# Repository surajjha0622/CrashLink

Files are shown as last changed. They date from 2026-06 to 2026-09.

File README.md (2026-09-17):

# CrashLink

Hybrid **LTE + LoRa** Emergency Alert System for Reliable Accident Reporting

---

## Overview

CrashLink is a hybrid LTE + LoRa emergency alert system designed to transmit accident alerts even in areas with poor or no cellular network coverage.

The system consists of three different node types that work together to ensure emergency messages reach responders through either LTE or a LoRa relay network.

---

##  Problem

Road accidents frequently occur in remote areas where cellular connectivity is unreliable or unavailable. This can delay emergency notifications, increasing response time and reducing the chances of timely medical assistance.

---

##  Solution

CrashLink consists of three node types:

-  Vehicle Node
-  Relay Node
-  Gateway Node

When LTE coverage is available, alerts are sent directly over the cellular network.

If LTE is unavailable, CrashLink automatically switches to a LoRa relay network, forwarding the emergency message until it reaches a Gateway Node.

---

#  System Architecture

<p align="center">
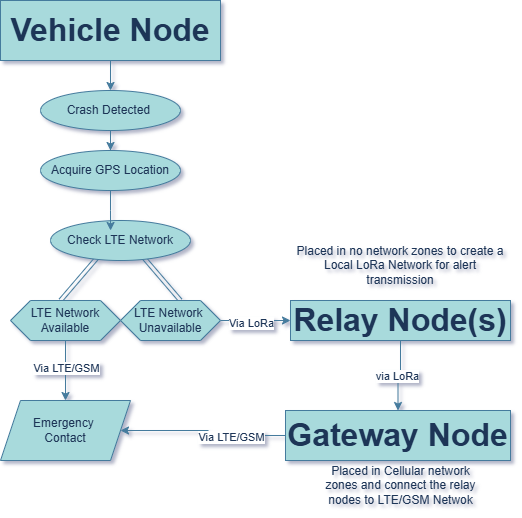
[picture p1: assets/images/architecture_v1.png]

</p>

---

#  Vehicle Node

### PCB Views

| Top | Bottom |
|---|---|
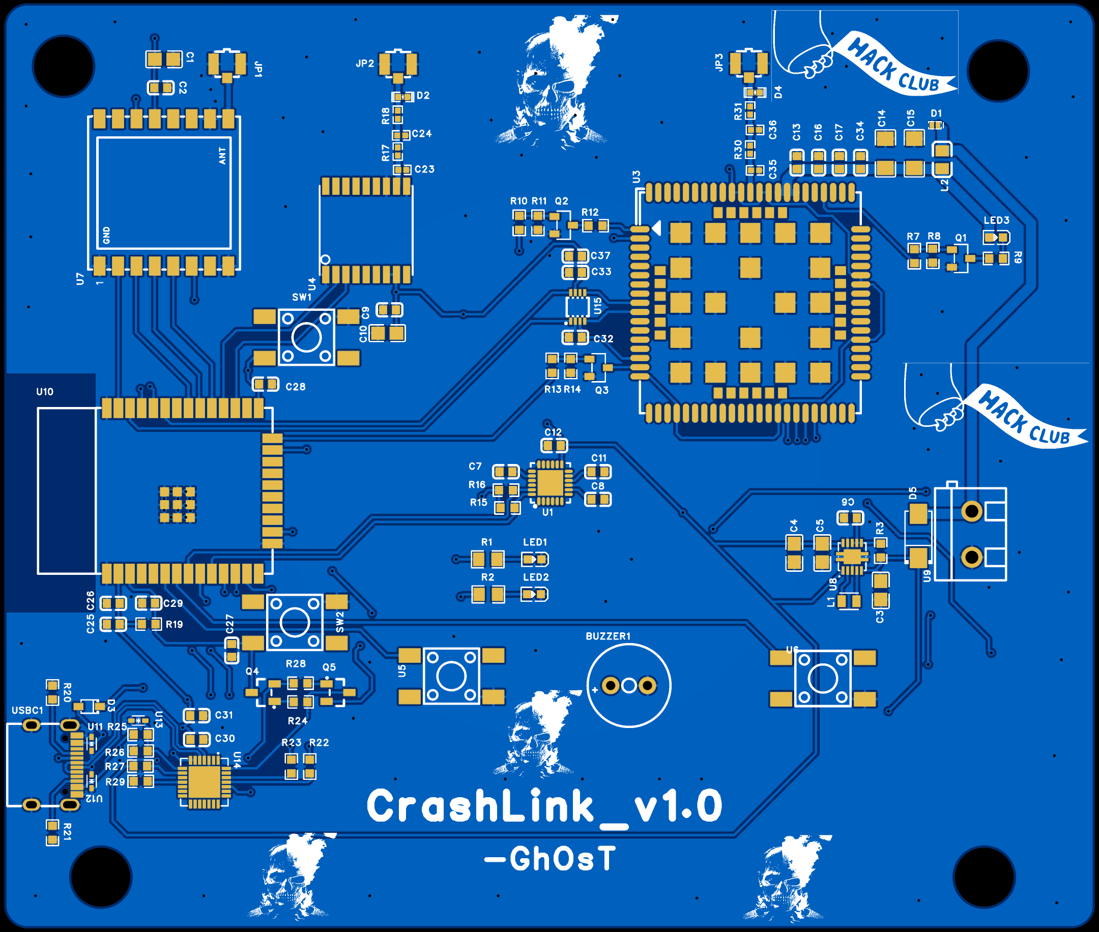
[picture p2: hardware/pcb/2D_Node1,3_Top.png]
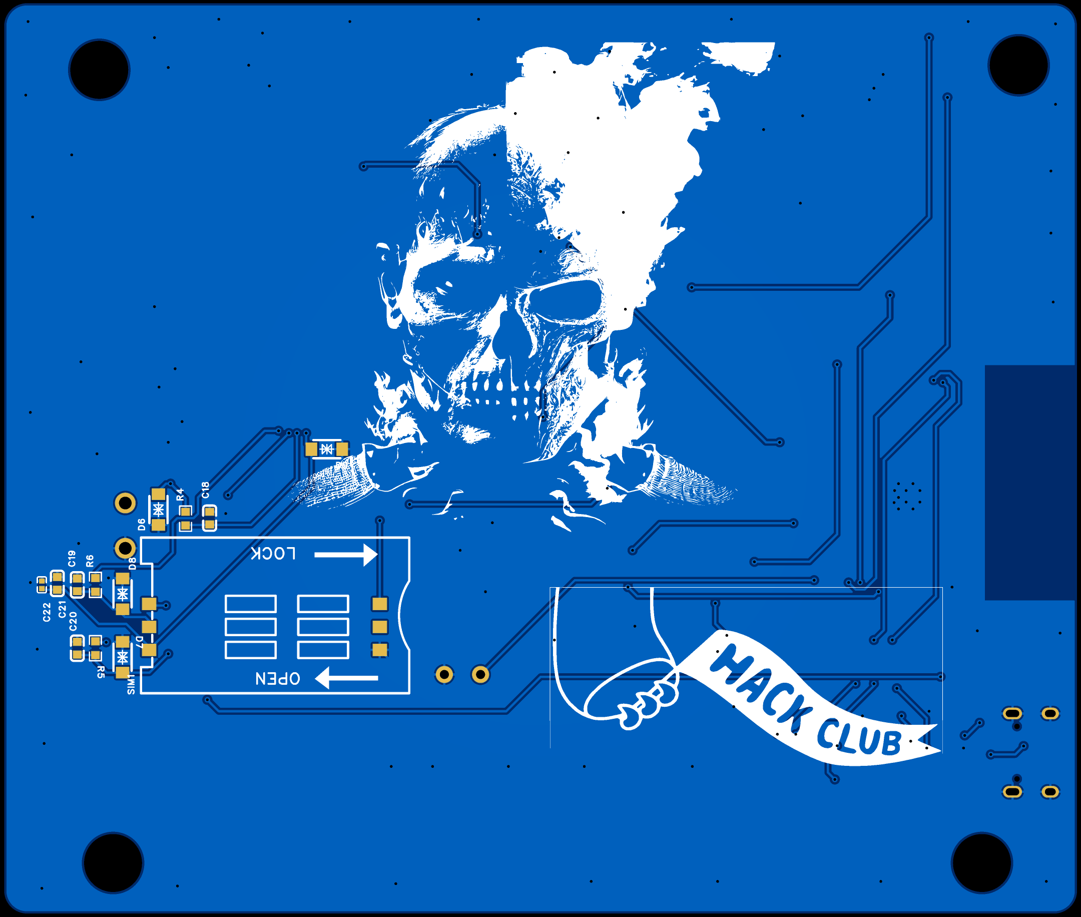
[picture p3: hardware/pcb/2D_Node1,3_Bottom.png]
|  |  |

### 3D Model

<p align="center">
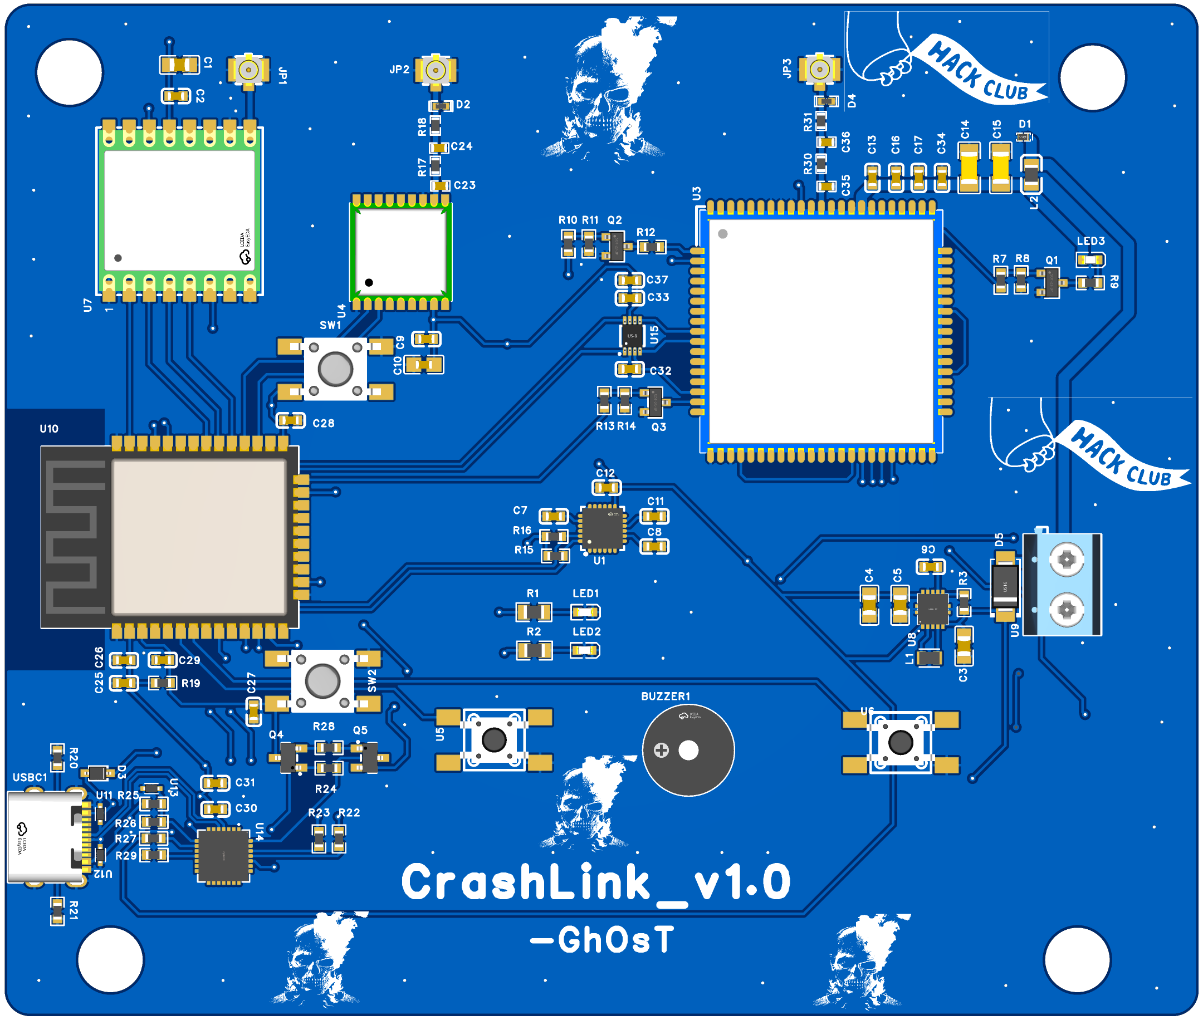
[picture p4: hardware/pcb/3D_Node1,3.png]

</p>

### Enclosure

<p align="center">
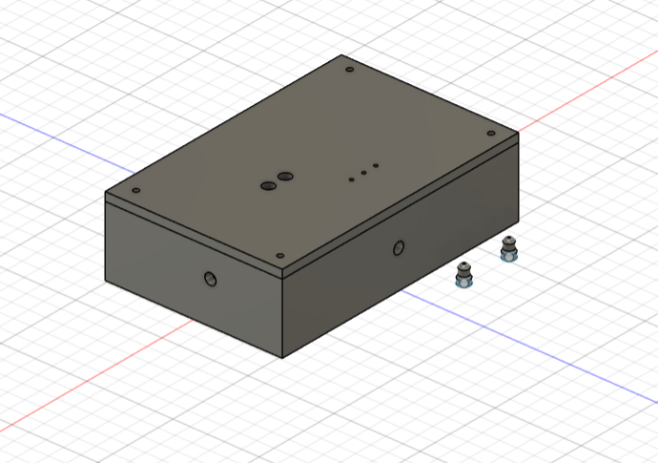
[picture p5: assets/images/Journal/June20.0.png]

</p>

---

#  Relay Node

### PCB Views

| Top | Bottom |
|---|---|
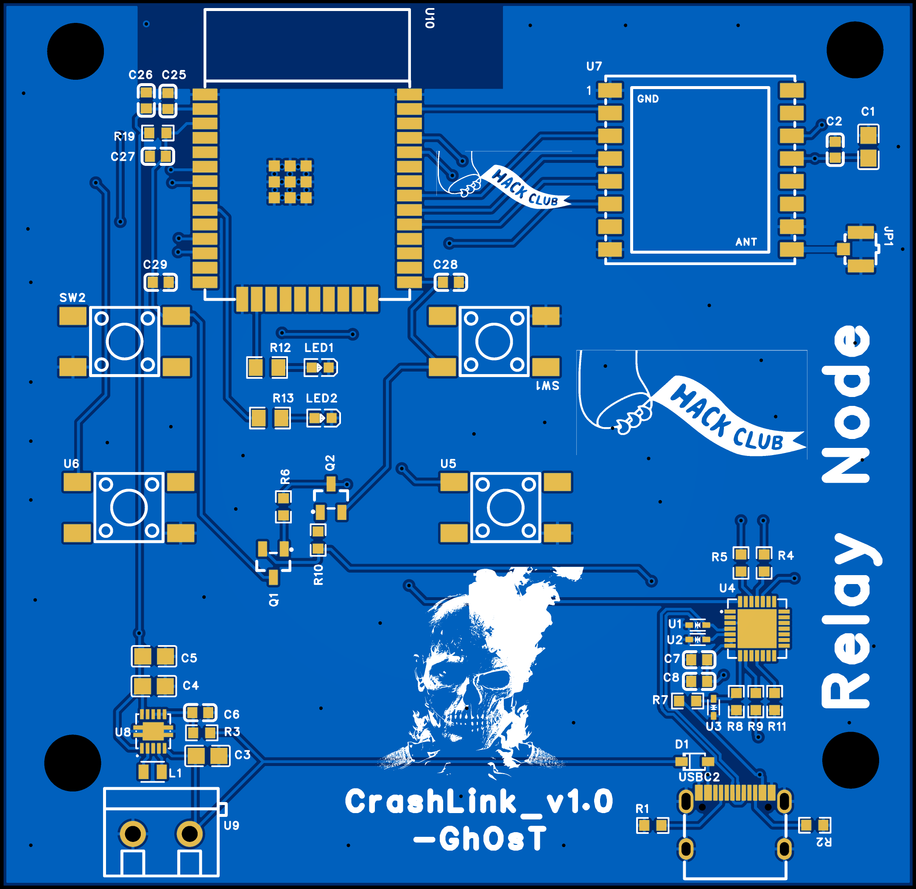
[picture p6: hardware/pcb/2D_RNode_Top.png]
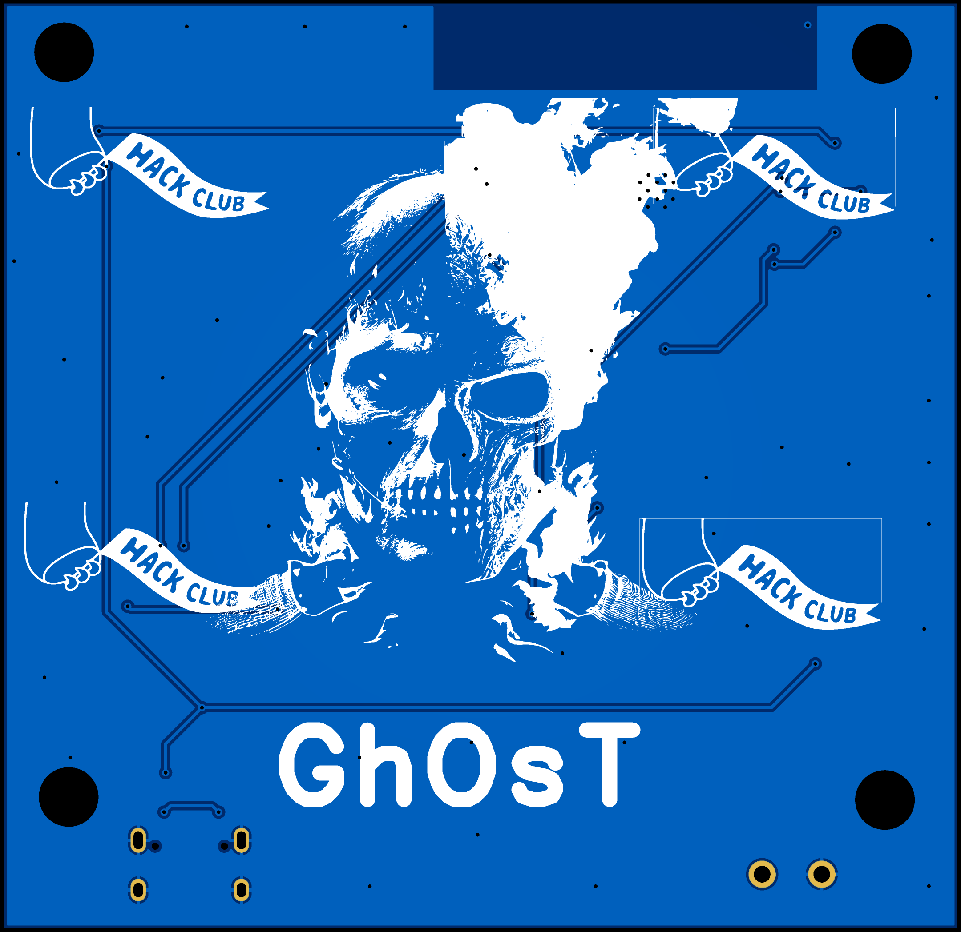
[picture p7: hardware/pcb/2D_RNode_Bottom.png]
|  |  |

### 3D Model

<p align="center">
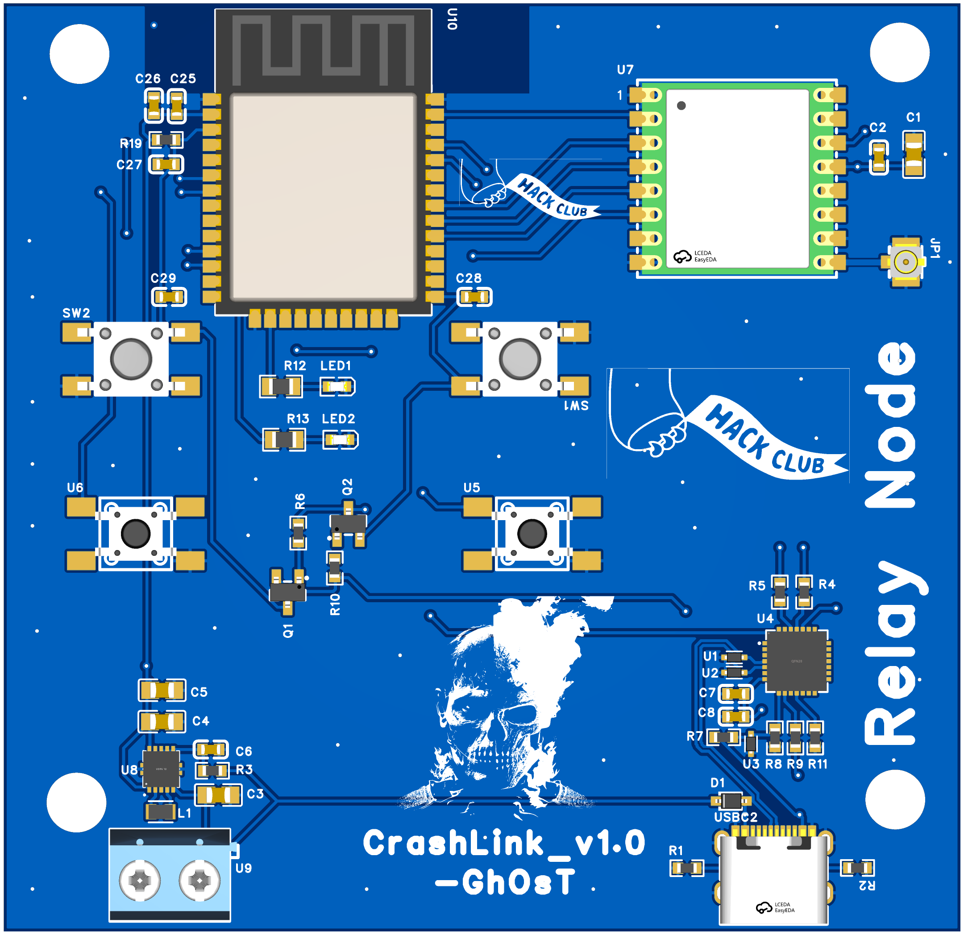
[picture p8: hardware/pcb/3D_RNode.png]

</p>

### Enclosure

<p align="center">
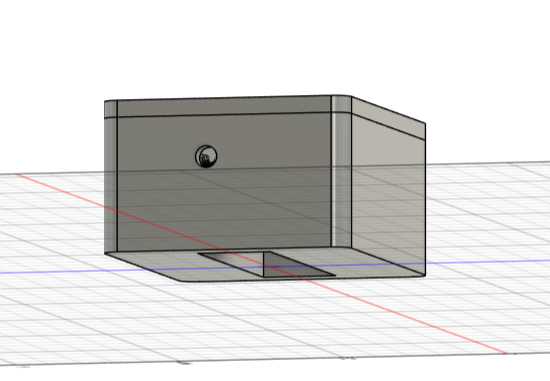
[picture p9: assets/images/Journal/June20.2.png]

</p>

---

#  Gateway Node

### PCB Views

| Top | Bottom |
|---|---|
|  |  |

### 3D Model

<p align="center">

</p>

### Enclosure

<p align="center">
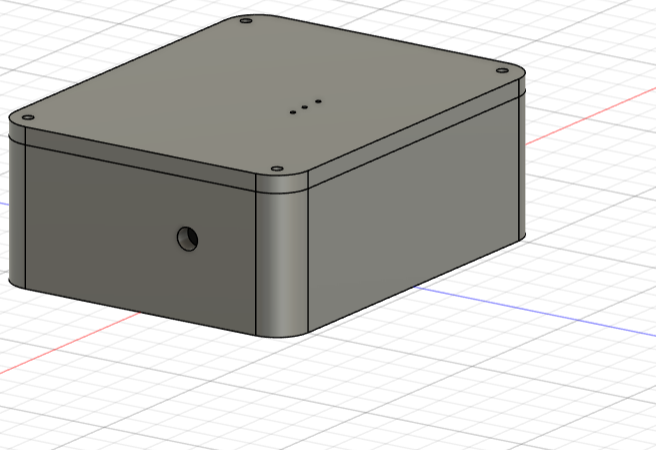
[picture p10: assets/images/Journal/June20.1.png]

</p>

---

#  BOM

## Core Electronics
 | Component | Qty | Purpose | Estimated Cost($) |
 |-----------|-----|---------|-------------------|
 | ESP32 | 3 | vehicle, Relay, Gateway controller| $15 |
 | SX1278 LoRa Module | 3 | LoRa communication  | $18 |
 | A7670 LTE Module | 2 | Vehicle LTE, Gateway LTE | $28 |
 | MAX10S GPS Module | 1 | Vehicle GPS | $12 |
 | MPU6050 | 1 | Vehicle | $4 |
 | Buck converter | 5 | Vehicle 2, Relay 1, Gateway 2| $10 |
 
 ## RF Components
 | Component | Qty | Purpose | Estimated Cost($) |
 |-----------|-----|---------|-------------------|
 | LoRa antenna | 3 | vehicle, Relay, Gateway | $9 |
 | LTE Antenna | 2 | Vehicle, Relay, Gateway | $10 |
 | U.FL/IPEX Cable | 8 | Antenna connections | $16 |

 ## Power System
 | Component | Qty | Purpose | Estimated Cost($) |
 |-----------|-----|---------|-------------------|
 | Li-ion Battery | 3 | Power source 1 each for Vehicle, Relay & Gateway | $25 |
 | Battery Connector/Holder | 4 | Battery Integration | $3 |
 | BMS/Protection module | 3 | Battery protection | $4 |

## PCB Fabrication
| Component | Qty | Purpose | Estimated Cost($) |
 |-----------|-----|---------|-------------------|
 | Vehicle Node PCB | 5 | Protoype fabrication |$15  |
 | Relay Node PCB | 5 | Protoype fabrication | $10 |
 | Gateway Node PCB | 5 | Protoype fabrication | $15 |

## Mechanical Components
 | Component | Qty | Purpose | Estimated Cost($) |
 |-----------|-----|---------|-------------------|
 |3D Printed Vehicle Enclosure | 1 | Housing | $10 |
 |3D Printed Vehicle Enclosure | 1 | Housing | $8 |
 |3D Printed Vehicle Enclosure | 1 | Housing | $10 |
 | M3 Screws Nuts & Standoffs | 1 Kit | assembly | $2 |

## Assembly Components
 
 | Component | Qty | Purpose | Estimated Cost($) |
 |-----------|-----|---------|-------------------|
 | LEDs | 10 | status indication  | $1  |
 | Push Buttons | 5 | User interaction | $1 |
 | Header pins | 2 Packs | Module connections| $3 |
 | JST connectors | 10 | battery and Power connections| $2 |
 | Screw terminals | 10 | Wiring | $2 |
 | Jumper Wires | 1 Kit | Prototyping | $3 |
 | Heat Shrink Tubing | 1 Kit | wire insulation | $4 |

 ## Assembly Tools
 | Component | Qty | Purpose | Estimated Cost($) |
 |-----------|-----|---------|-------------------|
 | Soldering Station | 1 | PCB assembly | $45 |
 | Solder Wire | 1 | Soldering | $5 |
 | Flux | 1 | Soldering | $5 |
 | Fume Extractor | 1 | Indoor solering safety | $20 |

## Notes
 - Quantities may be adjusted during prototype testing and validiation.

 ## Estimates Budget
 | Category | Estimated Cost ($) |
 |----------|--------------------|
 | Core Electronics | $87 |
 | RF Components | $35 |
 | Power System | $32 |
 | PCB Fabrication | $40 |
 | Mechanical Components | $30 |
 | Assembly Components | $16 | 
 | Assembly Tools | $75 |
 | **Total** | $315 |

#  License

This project is licensed under the MIT License.

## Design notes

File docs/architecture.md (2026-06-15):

# Crashlink Architecture

## Goal

Crashlink is a hybrid emergency alert system for vehicles.

Architecture

when cellular network is available then it uses LTE/GSM.

when network is not available in the area in consideration then it uses LoRa relay network to send the alert to nearest Gateway node.

Gateway node then transfers the alert via LTE/GSM.
Gateway nodes are strategically placed in the network available zones only.

## Vehicle node

 It detects the crash using the inputs from IMU and collect the GPS data from the GPS module.
 Now it scans for the availability of cellular network. If the network is available then it sends the alert signal via LTE and if the cellular coverage is not there then it sends the alert via LoRa over the LoRa network.

 ## Relay Node(s)
 It Recieves alerts from vehicle Node and Retransmits it if certain conditions are met.
 The Relay node(s) covers the area of no cellular coverage, acting as a backup fallback network and a bridge between the Vehicle Node and the Gateway Node.

 ## Gateway Node

 It is strategically placed to cover both the Relay node and cellular coverage in its range.
 This enable it to recieve the alerts from the Relay nodes and send alert over to cellular network.

Thus the system uses the cellular network coverage which is already available while also fills the gaps of no cellular connectivity and that too at low cost.

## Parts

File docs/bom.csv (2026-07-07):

Category | Component | Qty | Purpose | Estimated Cost ($)
Core Electronics | ESP32 | 4 | Vehicle, Relay, Gateway and spare controller | 20
Core Electronics | SX1278 LoRa Module | 4 | LoRa communication and spare | 24
Core Electronics | A7670 LTE Module | 3 | Vehicle LTE, Gateway LTE and spare | 40
Core Electronics | NEO-6M GPS Module | 2 | Vehicle GPS and spare | 12
Core Electronics | MPU6050 | 2 | Vehicle and spare | 4
Core Electronics | Buck Converter | 5 | Vehicle 2, Relay 1, Gateway 2 | 10
RF Components | LoRa Antenna | 4 | Vehicle, Relay, Gateway and spare | 12
RF Components | LTE Antenna | 3 | Vehicle, Relay, Gateway and spare | 15
RF Components | U.FL/IPEX Cable | 8 | Antenna connections | 16
Power System | Li-ion Battery | 6 | Power source (2 each for Vehicle, Relay & Gateway) | 25
Power System | Battery Connector/Holder | 4 | Battery integration | 3
Power System | BMS/Protection Module | 3 | Battery protection | 4
PCB Fabrication | Vehicle Node PCB | 5 | Prototype fabrication | 15
PCB Fabrication | Relay Node PCB | 5 | Prototype fabrication | 10
PCB Fabrication | Gateway Node PCB | 5 | Prototype fabrication | 15
Mechanical Components | 3D Printed Vehicle Enclosure | 1 | Housing | 10
Mechanical Components | 3D Printed Relay Enclosure | 1 | Housing | 8
Mechanical Components | 3D Printed Gateway Enclosure | 1 | Housing | 10
Mechanical Components | M3 Screws, Nuts & Standoffs | 1 Kit | Assembly | 2
Assembly Components | LEDs | 10 | Status indication | 1
Assembly Components | Push Buttons | 5 | User interaction | 1
Assembly Components | Header Pins | 2 Packs | Module connections | 3
Assembly Components | JST Connectors | 10 | Battery and power connections | 2
Assembly Components | Screw Terminals | 10 | Wiring | 2
Assembly Components | Jumper Wires | 1 Kit | Prototyping | 3
Assembly Components | Heat Shrink Tubing | 1 Kit | Wire insulation | 4
Assembly Tools | Soldering Iron | 1 | PCB assembly | 25
Assembly Tools | Solder Wire | 1 | Soldering | 5
Assembly Tools | Flux | 1 | Soldering | 5
Assembly Tools | Fume Extractor | 1 | Indoor soldering safety | 20

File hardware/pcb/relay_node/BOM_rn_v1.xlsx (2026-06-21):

No. | Quantity | Comment | Designator | Footprint | Value | Manufacturer Part | Manufacturer | Supplier Part | Supplier
1 | 5 | 10uF | C1,C3,C4,C5,C9 | C0805 | 10uF | CL21A106KAYNNNE | SAMSUNG(三星) | C15850 | LCSC
2 | 3 | 100nF | C2,C6,C10 | C0603 | 100nF | CC0603KRX7R9BB104 | YAGEO(国巨) | C14663 | LCSC
3 | 1 | 6GHz | JP1 | RF-SMD_FRF05002-JSS103M | 6GHz | U.FL-R-SMT-1(80) | HRS(广濑) | C88374 | LCSC
4 | 1 | 2.2uH | L1 | IND-SMD_L2.0-W1.2-MWTC201208S2R2MT | 2.2uH | APH201210C2R2MP01 | APV(爱普微) | C42455275 | LCSC
5 | 2 | XL-1608SURC-06 | LED1,LED2 | LED0603-RD_RED |  | XL-1608SURC-06 | XINGLIGHT(成兴光) | C965799 | LCSC
6 | 2 | 330mΩ | R1,R2 | R0805 | 330mΩ | 0805W8J033KT5E | UNI-ROYAL(厚声) | C31973 | LCSC
7 | 1 | 100Ω | R3 | R0603 | 100Ω | 0603WAF1000T5E | UNI-ROYAL(厚声) | C22775 | LCSC
8 | 1 | ESP32-S3 | U2 | COMM-TH_43.2-W17.8-P2.54_ESP32-S3 |  | ESP32-S3 | Waveshare(微雪电子) | C22438991 | LCSC
9 | 1 | RFM95W-915S2 | U7 | WIRELM-SMD_16P-L16.0-W16.0-P2.00_LORA-CC68-915MHZ-TCXO |  | RFM95W-915S2 | RF Solutions | C6760738 | LCSC
10 | 1 | TPS63001DRCR | U8 | VSON-10_L3.0-W3.0-P0.50-TL-EP_TPS62410DRCR |  | TPS63001DRCR | TI(德州仪器) | C28060 | LCSC
11 | 1 | KF301-5.0-2P | U9 | CONN-TH_P5.00_KF301-5.0-2P |  | KF301-5.0-2P | KEFA(科发) | C474881 | LCSC

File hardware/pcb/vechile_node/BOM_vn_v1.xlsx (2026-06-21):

No. | Quantity | Comment | Designator | Footprint | Value | Manufacturer Part | Manufacturer | Supplier Part | Supplier
1 | 1 | 2.7kHz | BUZZER1 | BUZ-TH_BD9.0-P4.00-D0.6-FD | 2.7kHz | QMB-09B-03 | 华能 | C96256 | LCSC
2 | 7 | 10uF | C1,C3,C4,C5,C7,C9,C11 | C0805 | 10uF | CL21A106KAYNNNE | SAMSUNG(三星) | C15850 | LCSC
3 | 7 | 100nF | C2,C6,C8,C10,C12,C16,C21 | C0603 | 100nF | CC0603KRX7R9BB104 | YAGEO(国巨) | C14663 | LCSC
4 | 1 | 10pF | C13 | C0603 | 10pF | CL10C100JB8NNNC | SAMSUNG(三星) | C1634 | LCSC
5 | 2 | 100uF | C14,C15 | C1206 | 100uF | CL31A107MQHNNNE | SAMSUNG(三星) | C15008 | LCSC
6 | 1 | 1uF | C17 | C0603 | 1uF | CL10A105KB8NNNC | SAMSUNG(三星) | C15849 | LCSC
7 | 3 | 22pF | C18,C19,C20 | C0603 | 22pF | CL10C220JB8NNNC | SAMSUNG(三星) | C1653 | LCSC
8 | 1 | 33pF | C22 | C0402 | 33pF | C0402T330G5GCLTU | KEMET(基美) | C2416757 | LCSC
9 | 1 | 1N4148SOD-323 | D1 | SOD-323_L1.7-W1.3-LS2.5-RD |  | 1N4148SOD-323 | JKSEMI(金开盛) | C2972761 | LCSC
10 | 3 | 6GHz | JP1,JP2,JP3 | RF-SMD_FRF05002-JSS103M | 6GHz | U.FL-R-SMT-1(80) | HRS(广濑) | C88374 | LCSC
11 | 1 | 2.2uH | L1 | IND-SMD_L2.0-W1.2-MWTC201208S2R2MT | 2.2uH | APH201210C2R2MP01 | APV(爱普微) | C42455275 | LCSC
12 | 1 | BLM21PG300SN1D | L2 | L0805 |  | BLM21PG300SN1D | muRata(村田) | C16903 | LCSC
13 | 2 | XL-1608SURC-06 | LED1,LED2 | LED0603-RD_RED |  | XL-1608SURC-06 | XINGLIGHT(成兴光) | C965799 | LCSC
14 | 1 | 19-217/GHC-YR1S2/3T | LED3 | LED0603-RD |  | 19-217/GHC-YR1S2/3T | EVERLIGHT(亿光) | C72043 | LCSC
15 | 3 | MMBT3904(RANGE:100-300) | Q1,Q2,Q3 | SOT-23-3_L2.9-W1.3-P1.90-LS2.4-BR |  | MMBT3904(RANGE:100-300) | CJ(江苏长电/长晶) | C20526 | LCSC
16 | 2 | 330mΩ | R1,R2 | R0805 | 330mΩ | 0805W8J033KT5E | UNI-ROYAL(厚声) | C31973 | LCSC
17 | 1 | 100Ω | R3 | R0603 | 100Ω | 0603WAF1000T5E | UNI-ROYAL(厚声) | C22775 | LCSC
18 | 3 | 22Ω | R4,R5,R6 | R0603 | 22Ω | 0603WAF220JT5E | UNI-ROYAL(厚声) | C23345 | LCSC
19 | 5 | 4.7kΩ | R7,R10,R13,R15,R16 | R0603 | 4.7kΩ | 0603WAF4701T5E | UNI-ROYAL(厚声) | C23162 | LCSC
20 | 3 | 47kΩ | R8,R11,R14 | R0603 | 47kΩ | 0603WAF4702T5E | UNI-ROYAL(厚声) | C25819 | LCSC
21 | 2 | 1kΩ | R9,R12 | R0603 | 1kΩ | 0603WAF1001T5E | UNI-ROYAL(厚声) | C21190 | LCSC
22 | 1 | CCM033001LFTR102 | SIM1 | SIM-SMD_CCM033001LFTR102 |  | CCM033001LFTR102 |  | C9900003292 | LCSC
23 | 1 | MPU-6050 | U1 | QFN-24_L4.0-W4.0-P0.50-BL-EP2.7 |  | MPU-6050 | TDK InvenSense(应美盛) | C24112 | LCSC
24 | 1 | ESP32-S3 | U2 | COMM-TH_43.2-W17.8-P2.54_ESP32-S3 |  | ESP32-S3 | Waveshare(微雪电子) | C22438991 | LCSC
25 | 1 | A7670C-LANS | U3 | LGA-124_L24.0-W24.0-P1.0-A7670C-LASS |  | A7670C-LANS | SIMCOM(芯讯通无线科技) | C18548274 | LCSC
26 | 1 | NEO-6M-0-001 | U4 | GPSM-SMD_24P-L16.0-W12.2-P1.10 |  | NEO-6M-0-001 | U-BLOX(优北罗) | C32413118 | LCSC
27 | 2 | YZA-056-5.0 | U5,U6 | SW-SMD_4P-L4.5-W4.5-P3.00-LS6.8 |  | YZA-056-5.0 | YIZHI(逸致) | C49108648 | LCSC
28 | 1 | RFM95W-915S2 | U7 | WIRELM-SMD_16P-L16.0-W16.0-P2.00_LORA-CC68-915MHZ-TCXO |  | RFM95W-915S2 | RF Solutions | C6760738 | LCSC
29 | 1 | TPS63001DRCR | U8 | VSON-10_L3.0-W3.0-P0.50-TL-EP_TPS62410DRCR |  | TPS63001DRCR | TI(德州仪器) | C28060 | LCSC
30 | 1 | KF301-5.0-2P | U9 | CONN-TH_P5.00_KF301-5.0-2P |  | KF301-5.0-2P | KEFA(科发) | C474881 | LCSC

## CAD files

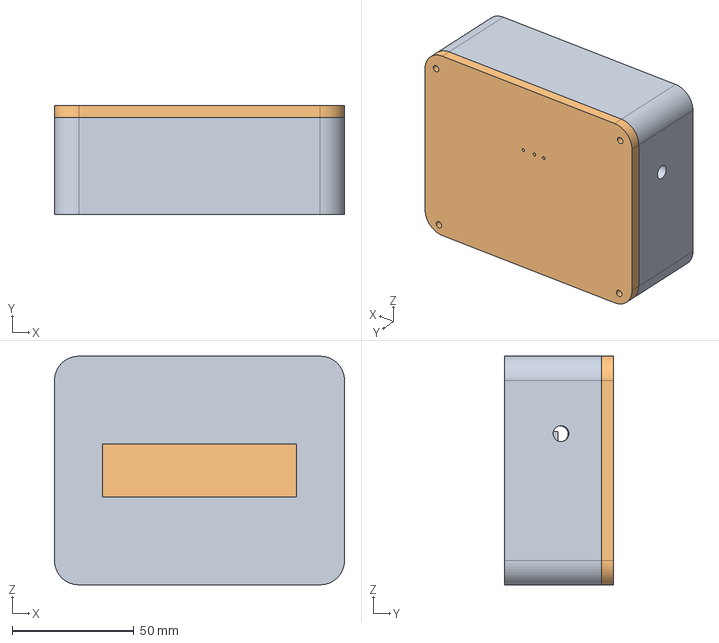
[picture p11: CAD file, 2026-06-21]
hardware/cad/gateway_node/GatewayCase_v1.step
119.3 x 45.0 x 94.1 mm

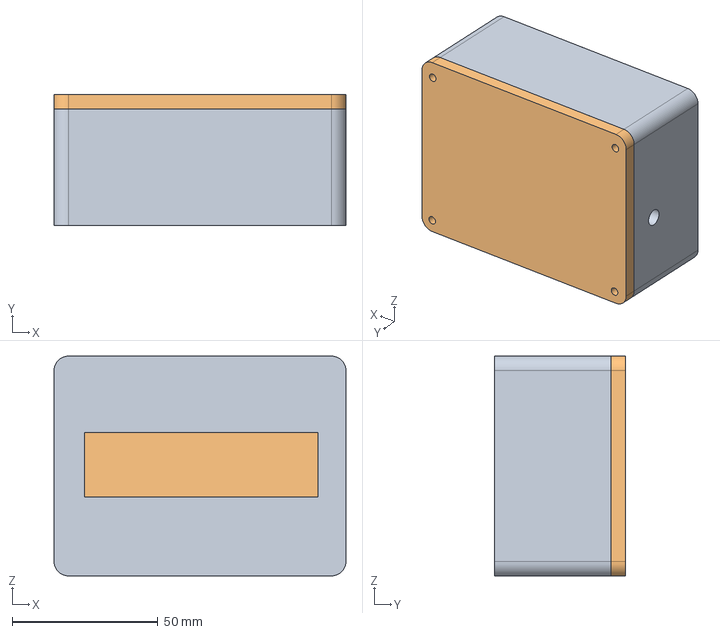
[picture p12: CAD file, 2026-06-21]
hardware/cad/relay_node/RelayCase_v1.step
100.0 x 45.0 x 75.3 mm

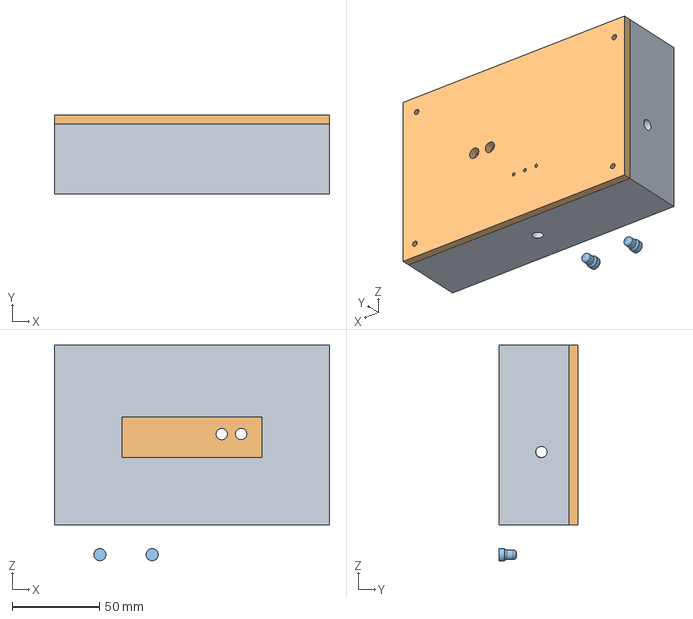
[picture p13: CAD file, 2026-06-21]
hardware/cad/vehicle_node/VehicleCase_v1.step
157.6 x 45.0 x 123.5 mm

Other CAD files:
archives/cad/vehicle_node/VehicleCase_v1.f3d
archives/cad/vehicle_node/VehicleCase_v1.stl
hardware/cad/vehicle_node/VehicleCase_v1.f3d
hardware/cad/vehicle_node/VehicleCase_v1.stl

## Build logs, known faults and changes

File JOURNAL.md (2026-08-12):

---
title: "CrashLink"
author: "SURAJ K. JHA"
description: "CrashLink is a hybrid LTE + LoRa based emergency alert system."
created_at: "2026-06-03"
---

# June 4: The Origin of idea & setting up github repo

Was walking on the roof and suddenly it clicked.
The road safety AI Hackathon I read about few days ago.
I wrote down the ideas came to my head.
How an automatic alert can save many people who
die cause no help reach to them quickly due to late information about crashes etc.
Planned the whole thing and visualised it in my head about
the flow of alert message and the placement of devices etc.

Architecture Diagram

**Total time spent: 1 hours**

# June 5: VS code setup and some coding aswell

Spent good time setting up VS code and configure everything properly.
also did some coding not much just wrote structure for all 3 nodes.
- Vehicle Node
- Relay Node
- Gateway Node

Did a bit extra for Vehicle node and added detectcrash() function for it.

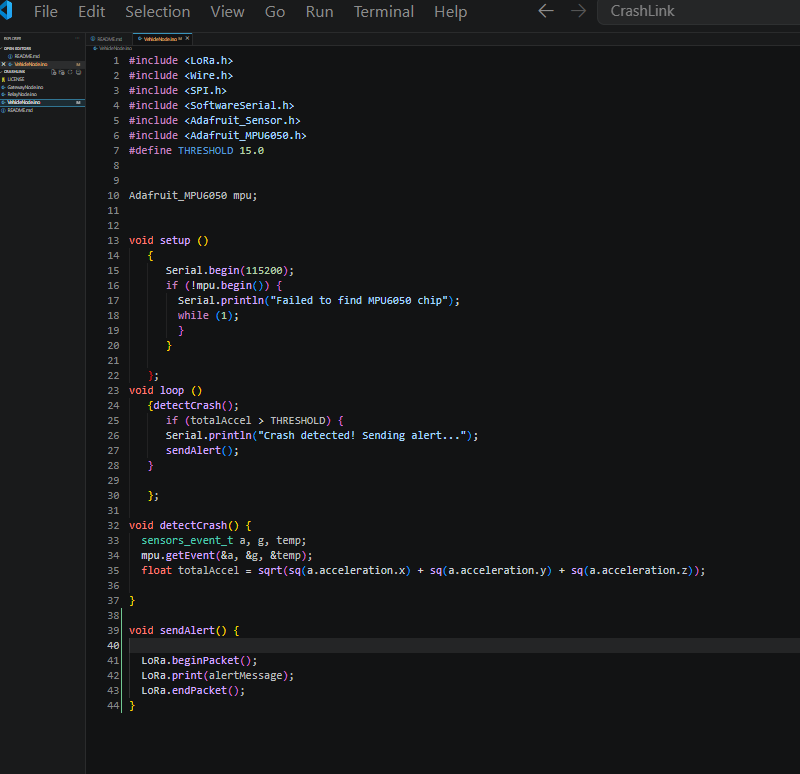
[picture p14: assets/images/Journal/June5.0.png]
Some Coding


**Total time spent: 1 hours**

# June 6: PCB design for Vehicle node
It felt i forgot everything coz last time I designed PCB was 1.5 years ago.
somehow I managed to do it although in the end i couldnt find how to place hole in this easy eda pro.

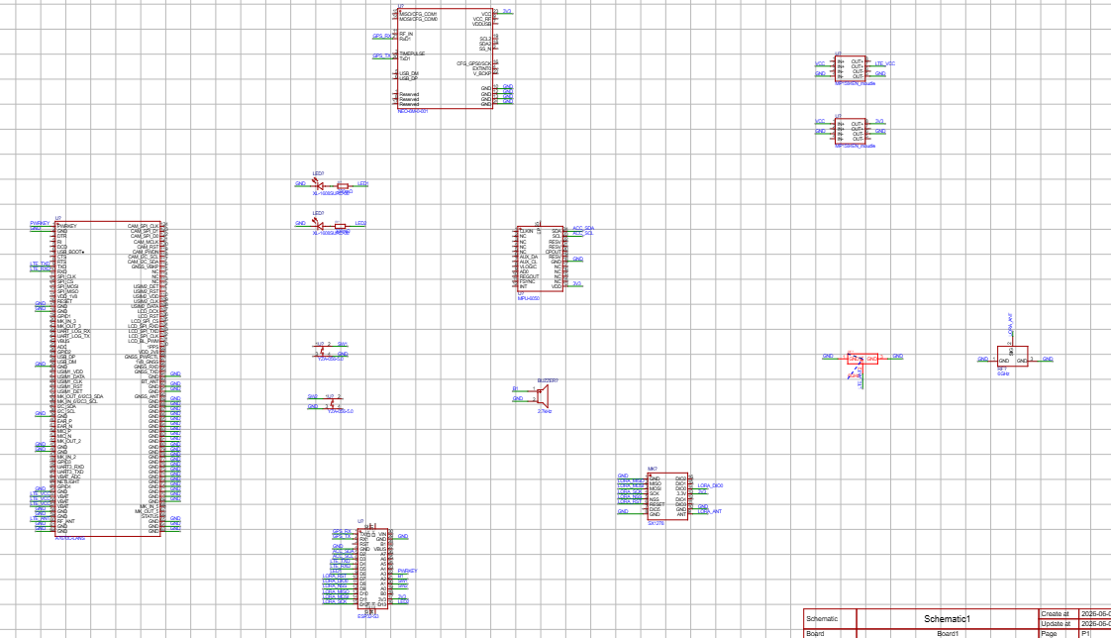
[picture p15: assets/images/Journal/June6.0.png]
Vehicle Node

- [Lapse Recording](https://lapse.hackclub.com/timelapse/vquPurF1DCEv)

**Total time spent: 4 hours**

# June 7: Architecture Diagram
Used draw.io to draw diagram of How the whole system will work. I felt amazing after looking at it because it simplified everything in the brain and I could feel the flow of commmunications through it.

Architecture Diagram

- [Lapse Recording](https://lapse.hackclub.com/timelapse/MV4wL9otCHe_)

**Total time spent: 1 hours 30 minutes**

# June 8 : Revised vechicle node PCB & Made Relay Node PCB
I redesigned the Vehicle node PCB and Revised its schematics. I basically re organized the components in Schematics dividing it into different sections like:
- Power
- Communication
- sensors
- Processing

Also i made Relay Node PCB schematics and PCB design

then I pushed the vehicle node PCB design gerbers and images to github.

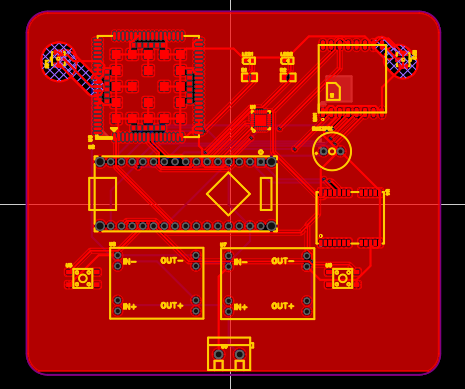
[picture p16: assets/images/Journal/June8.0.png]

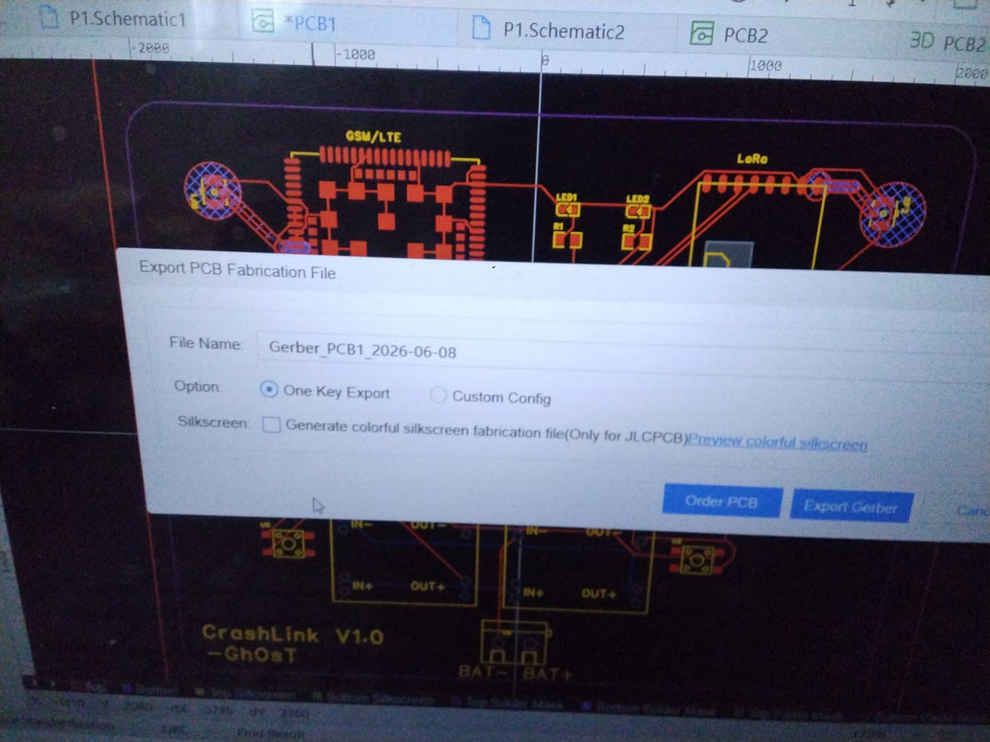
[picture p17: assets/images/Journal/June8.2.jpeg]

- [Lapse Recording](https://lapse.hackclub.com/timelapse/5CicOemg2tyk)

**Total time spent: 5 hours**

# June 9 : Documentation => Wrote README.md and spent some time reassesing pcb design
It is very frustrating to wite out and document things like this but I think this is what makes the other parts more intresting. so yeah i did wrote Readme folder and stared at PCB for few hours and yes very productive hours because i found nothing
also ended up unsatisfied with the README which i wrote.

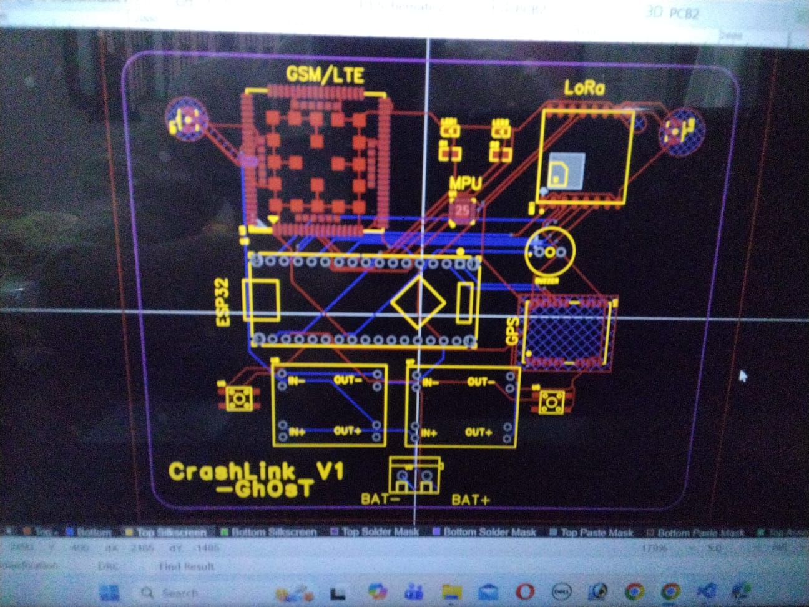
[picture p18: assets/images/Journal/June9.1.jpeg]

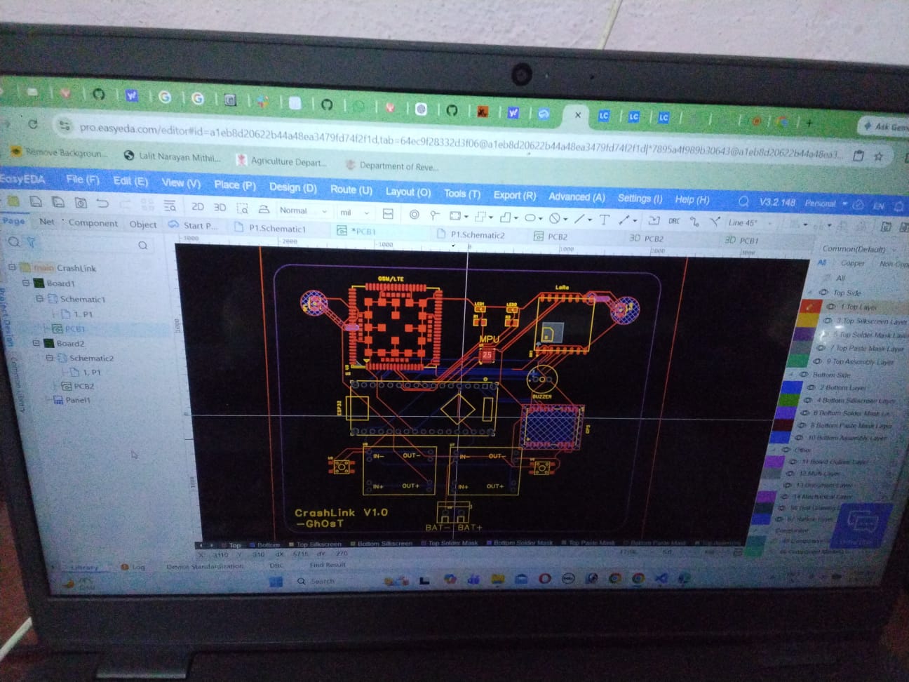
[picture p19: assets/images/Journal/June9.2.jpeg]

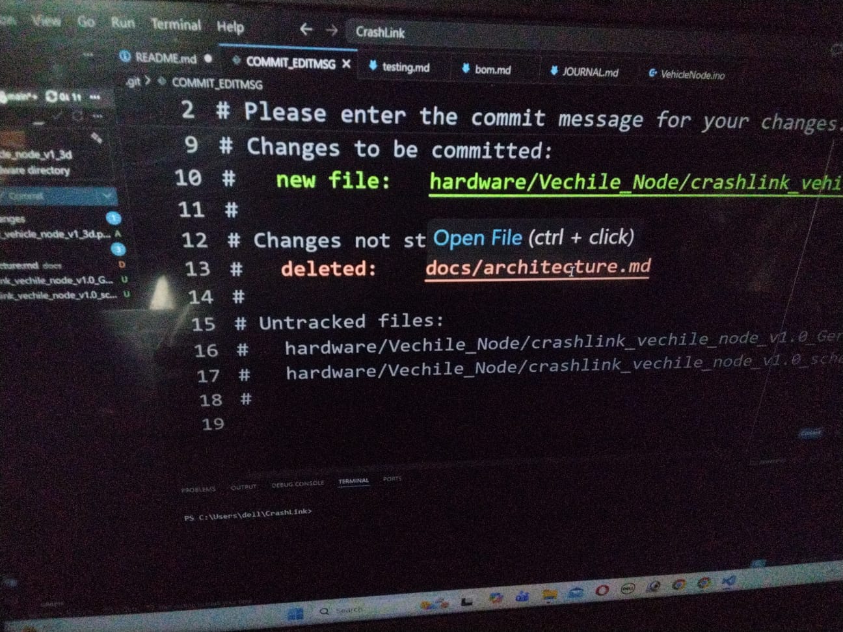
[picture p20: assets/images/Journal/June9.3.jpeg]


**Total time spent: 1 hours**

# June 10 : More Documentation => README, BOM
Spent some good time making BOM and in between I revisited to write Readme and i think its well written now... then i got back to working on the BOM i think its finally done.
I had to search multiple sites and compare the prices so it took too much time.

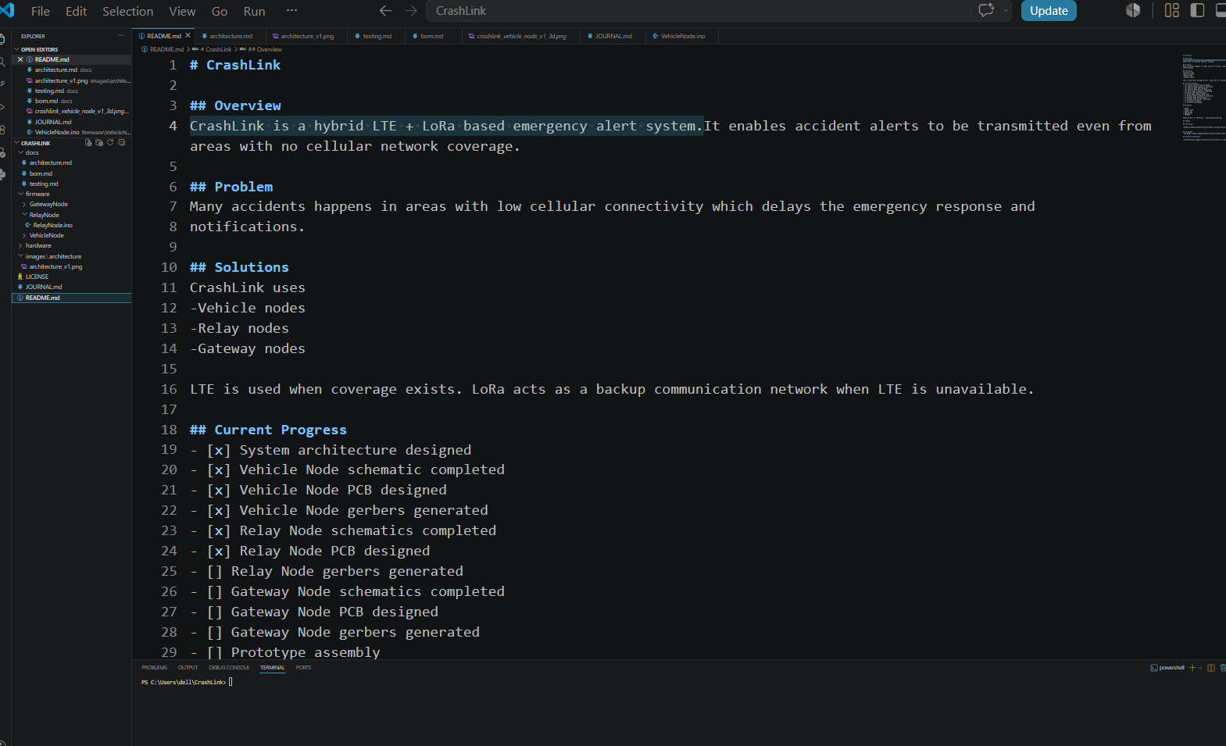
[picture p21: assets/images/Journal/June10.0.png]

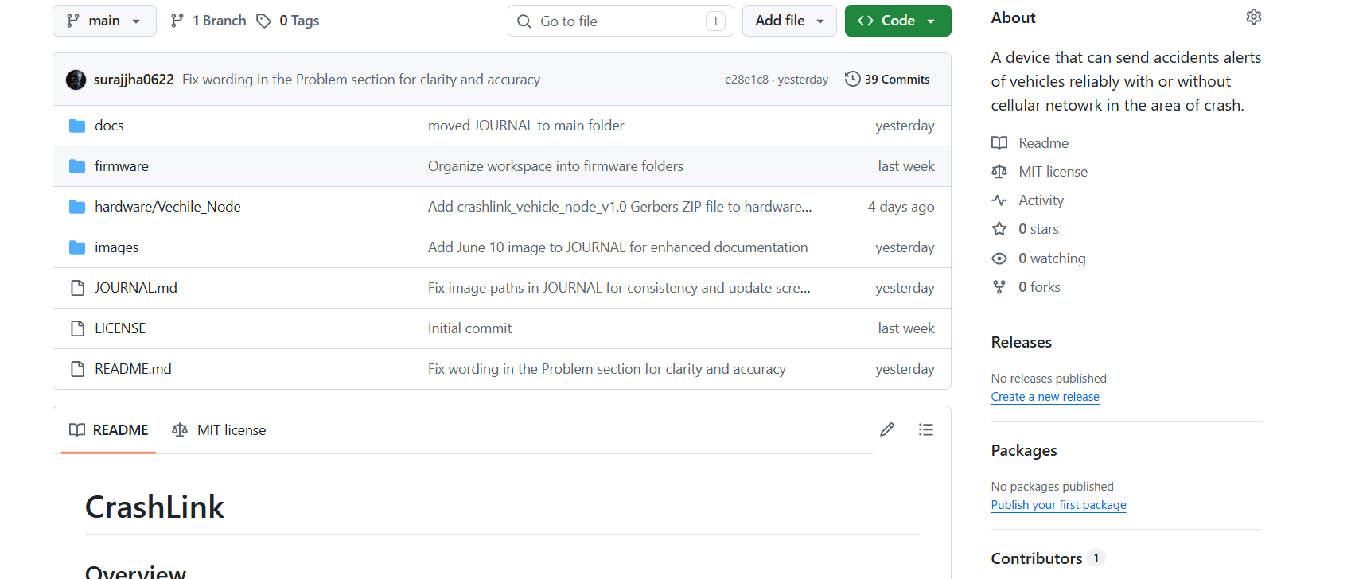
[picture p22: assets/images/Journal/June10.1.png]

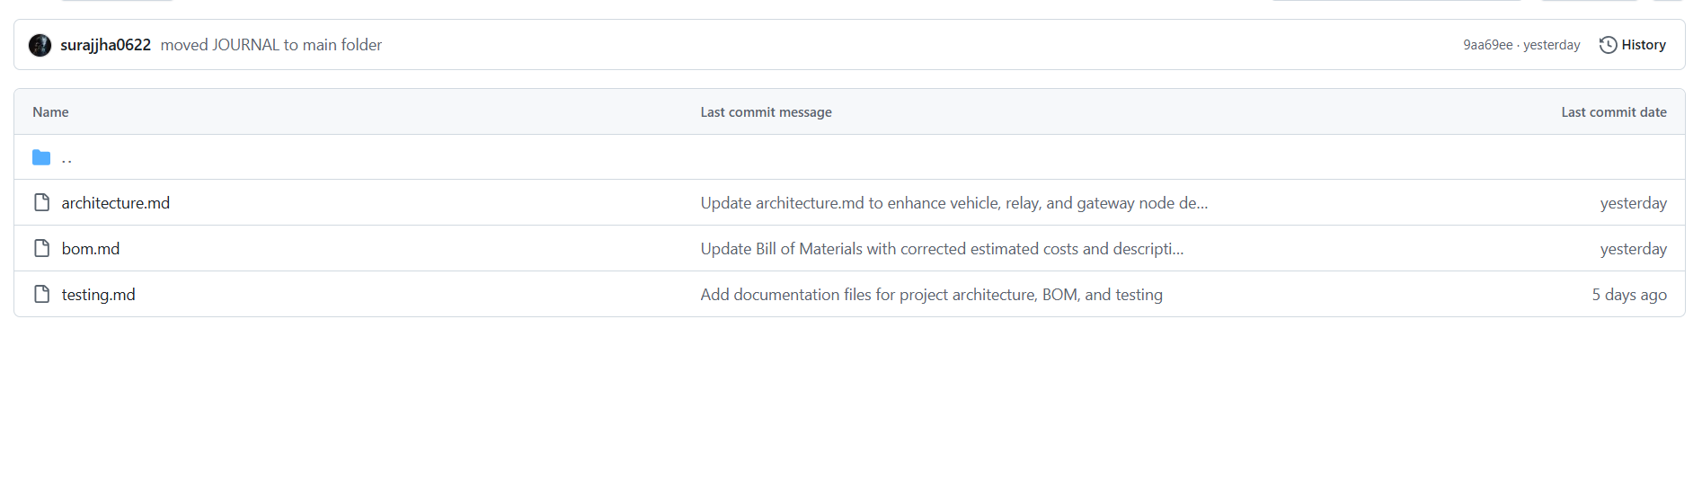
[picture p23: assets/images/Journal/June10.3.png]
Made BOM


**Total time spent: 4 hours**

# June 11 : Completed documentation & and pitched for forge
Finished importand documentation and submitted my pitch to forge slack channel.
Important documentation includes Final checks for BOM,README and overr all folder structure.

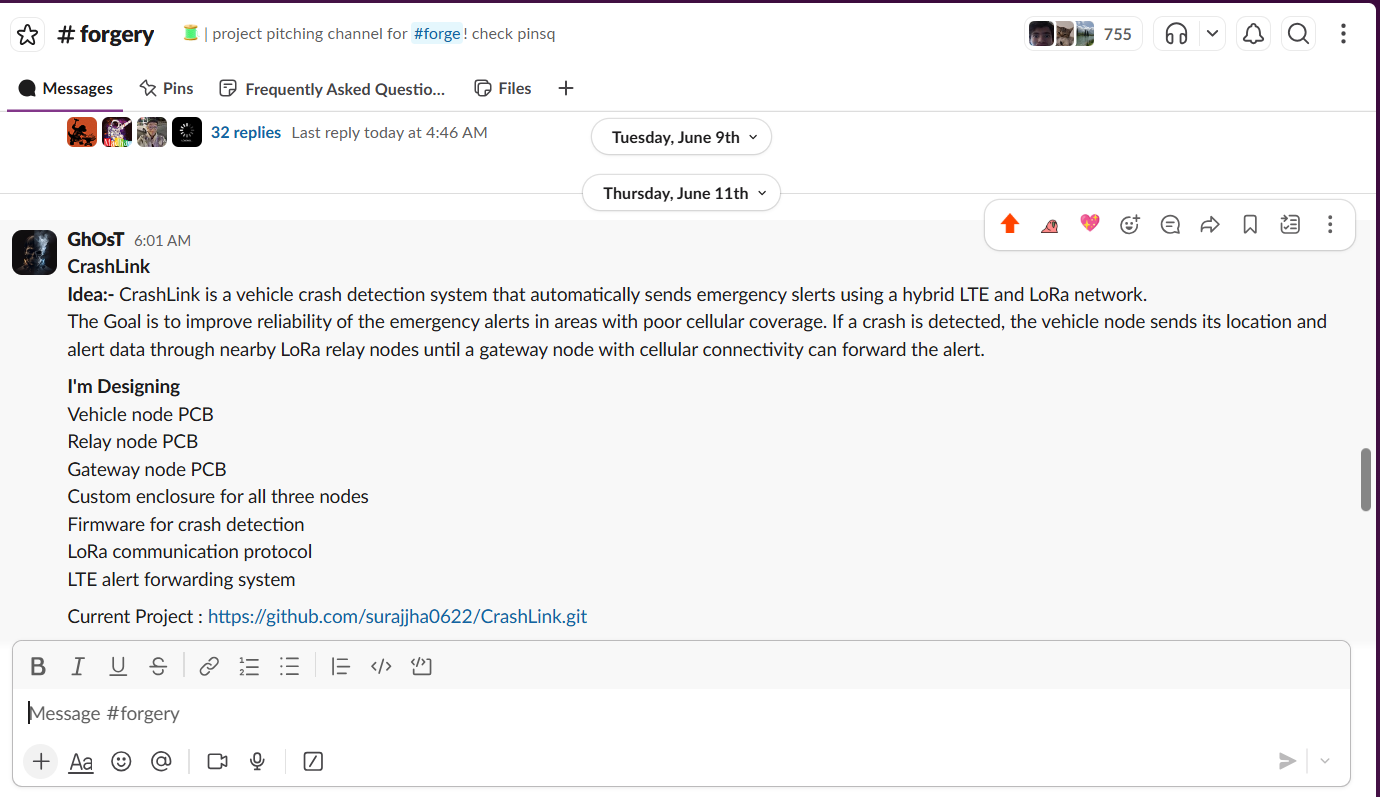
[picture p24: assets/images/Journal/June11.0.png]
Forge pitch


**Total time spent: 1 hours**

# June 12 : Big Blunder Reveal
So I was going through datasheets and doing some design reviews and and and I found out i didn't
include the sim socket in the PCB design well this was very stupid error i would say.

Also i didn't include power filter at voltage inputs(Decoupling capacitors).

then I fixed the journal timing thing idk why the hacktime is 1 day behind my actual work whatever....i do have lapse recordings.

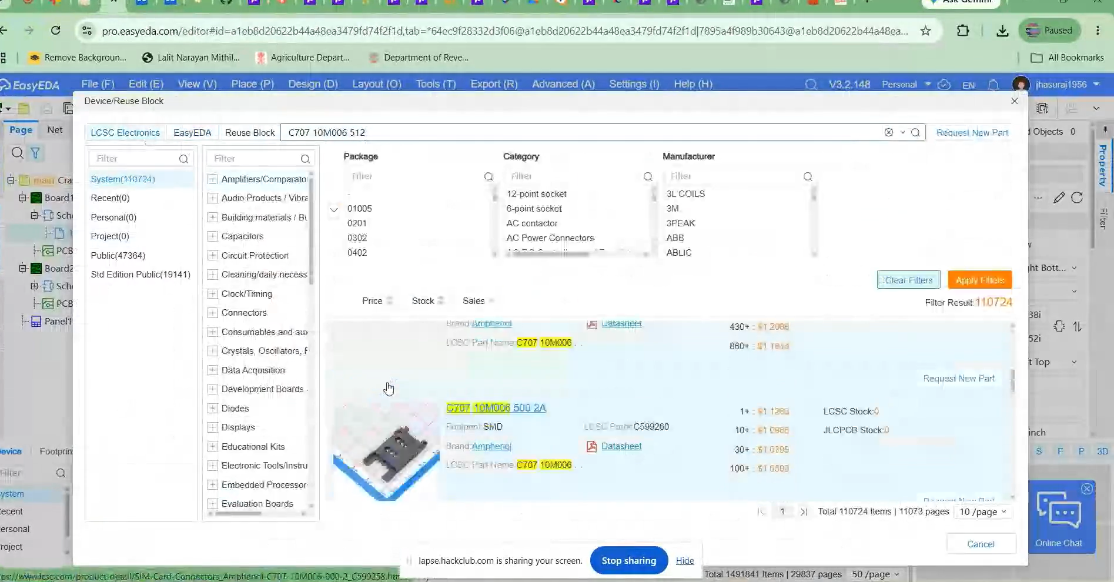
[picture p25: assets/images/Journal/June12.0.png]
Lapse screenshot

- [Journal Fixing](https://lapse.hackclub.com/timelapse/1WFZ6ML9bd7k)
- [Research + More Fixing](https://lapse.hackclub.com/timelapse/yP9O9QBxnpig)
- [More Research](https://lapse.hackclub.com/timelapse/8O7ItGtjQ06I)
- [Reviewing past work and more research](https://lapse.hackclub.com/timelapse/ehilIq9ZyCS3)

**Total time spent: 2 hours 30 minutes**

# June 13 : PCB Design Major part done 
I sit down with one goal in mind that was to finish the PCB Design work.I got done with the vehicle node pcb and 80% of the relay node aswell.
used reference designs from Datasheets and also added the sim socket which i missed last time.
Tbh lots of time it took to search for part number that is there in Easy EDA.

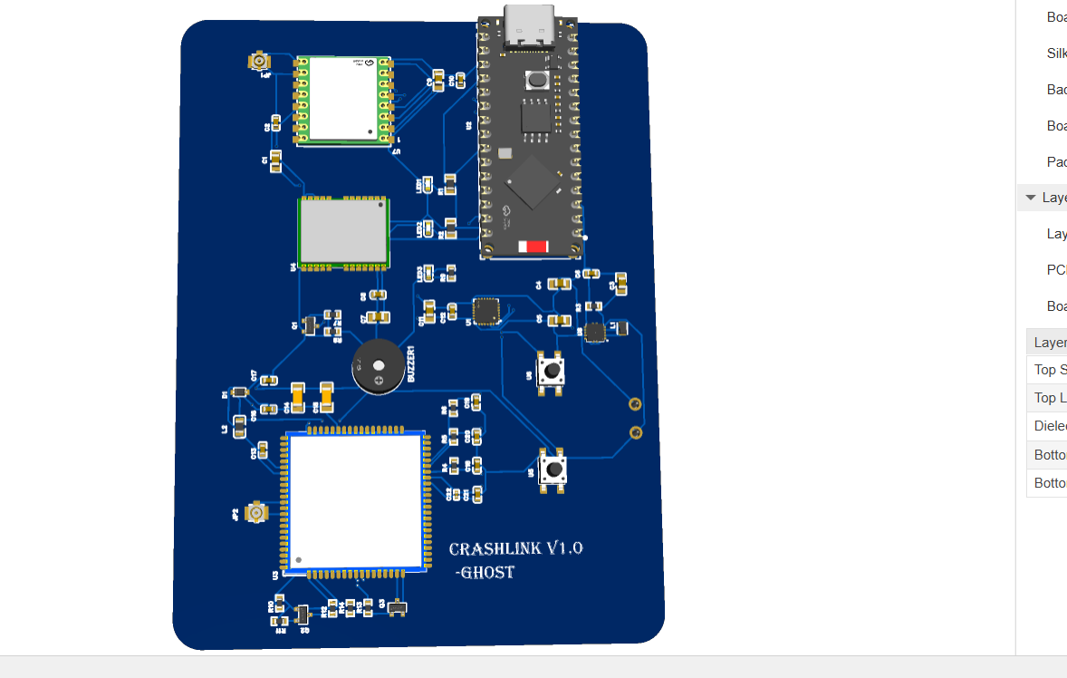
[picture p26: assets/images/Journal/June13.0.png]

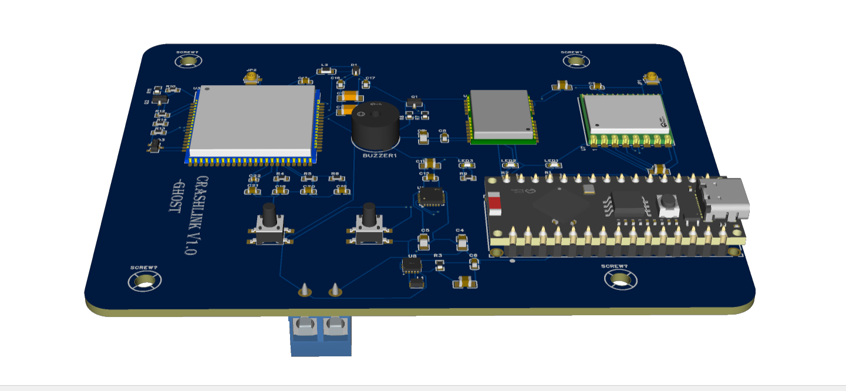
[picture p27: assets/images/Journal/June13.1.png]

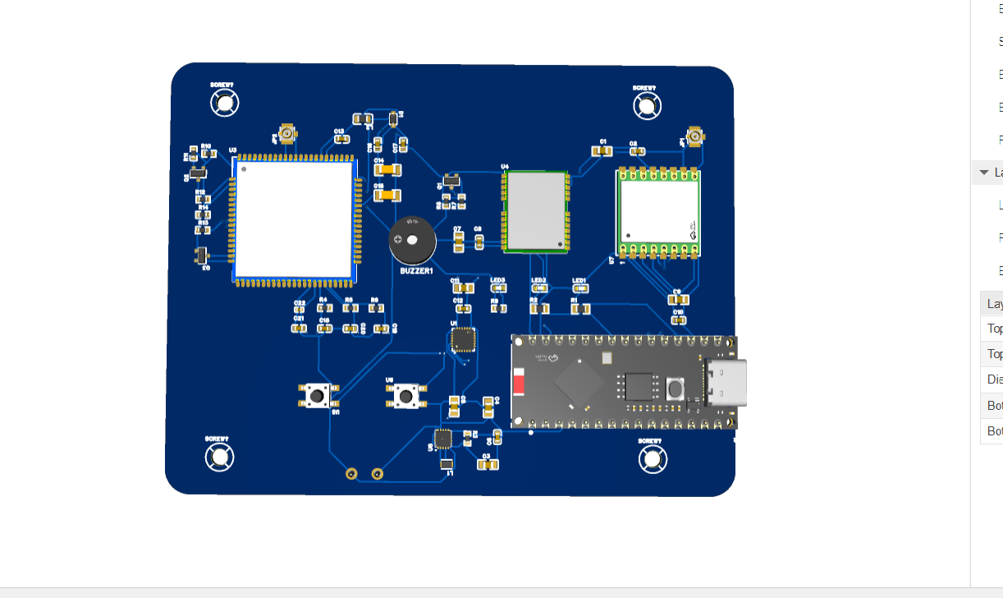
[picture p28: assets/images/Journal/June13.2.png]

- [Lapse PCB Designing](https://lapse.hackclub.com/timelapse/mqEL4IdIFe5i)
- [Lapse PCB Designing](https://lapse.hackclub.com/timelapse/OPMM19FXR9UI)

Also did some documentation around 30 min

**Total time spent: 4 hours 45 minutes**

# June 14 : Finishing the job for remaining
 So I had somer unfinished job from the relay node
 and also designing gateway node.
 at starting i thought it would be just a cope paste thing as schematics etc are same and yes it did made it a bit easy but the challanging part came....components placement and routing.
 I did complete the relay node pcb designing and exported them to push on github.

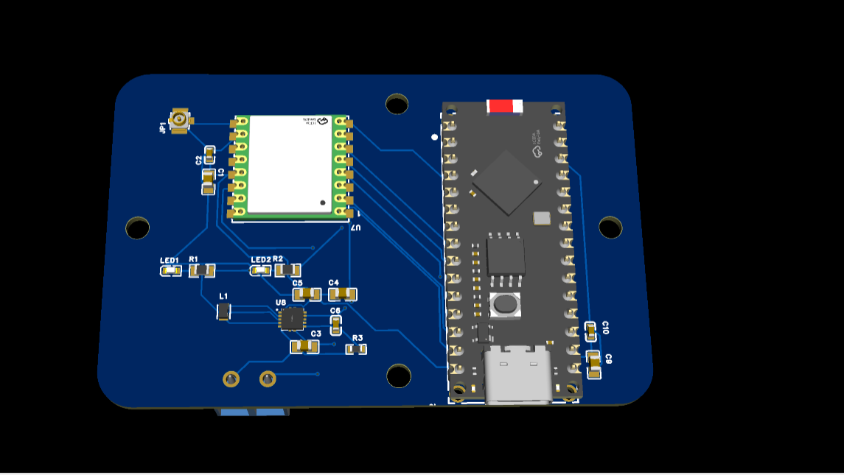
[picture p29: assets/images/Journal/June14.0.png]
Relay Node design

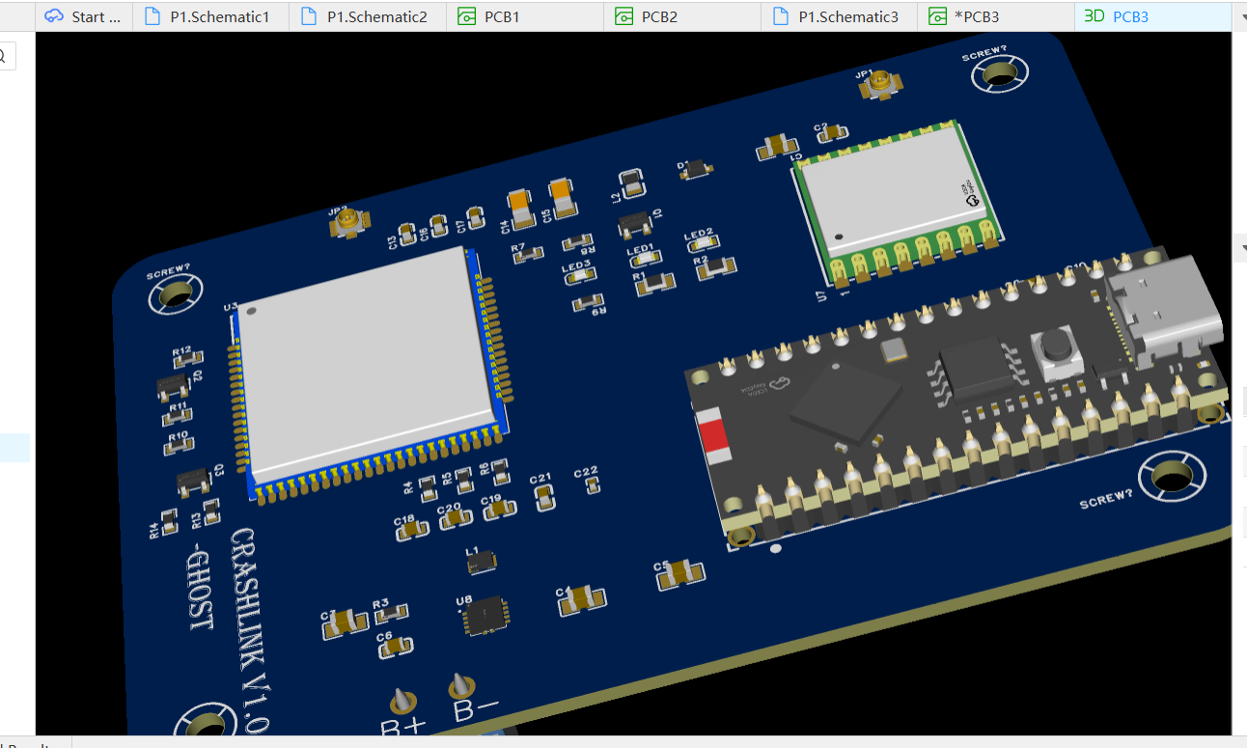
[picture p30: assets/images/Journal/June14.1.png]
Gateway Node design


- [Lapse PCB Designing](https://lapse.hackclub.com/timelapse/YgPzBqFPpGOS)

Also did some documentation around 25 min.

 **Total time spent: 5 hours**

# June 15 : Gateway Node PCB completed
Finally completed the PCB design for Gateway Node
also re organized the layout for Vehicle node and Relay node
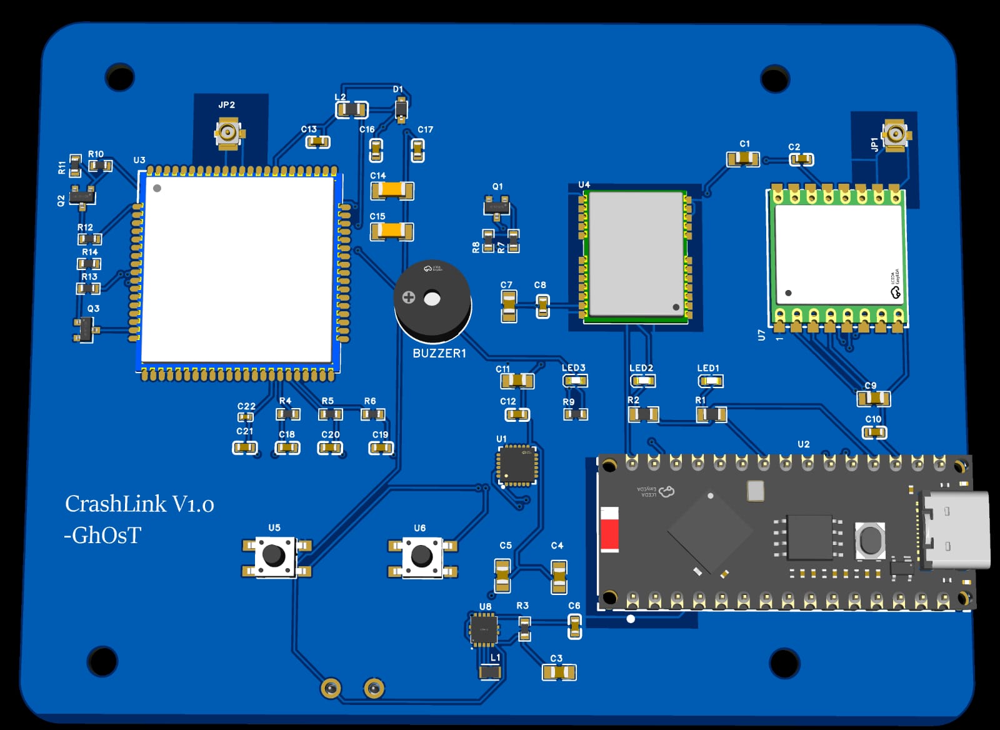
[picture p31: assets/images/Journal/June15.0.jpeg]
3D Vehicle Node

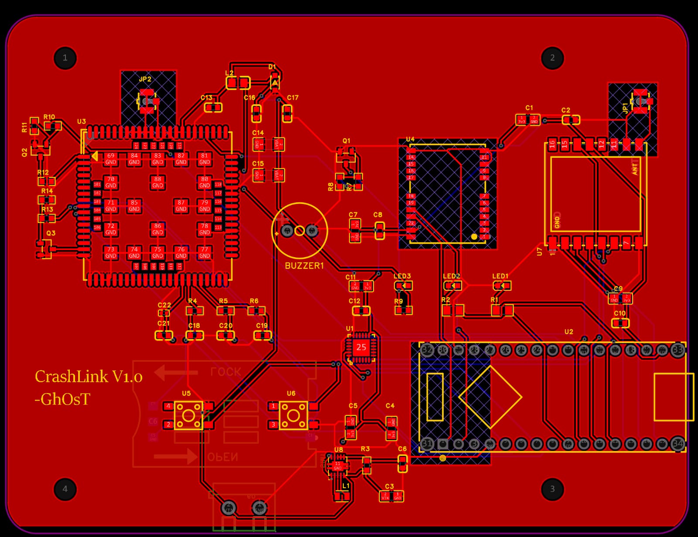
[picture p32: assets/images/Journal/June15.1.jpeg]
PCB Vehicle Node

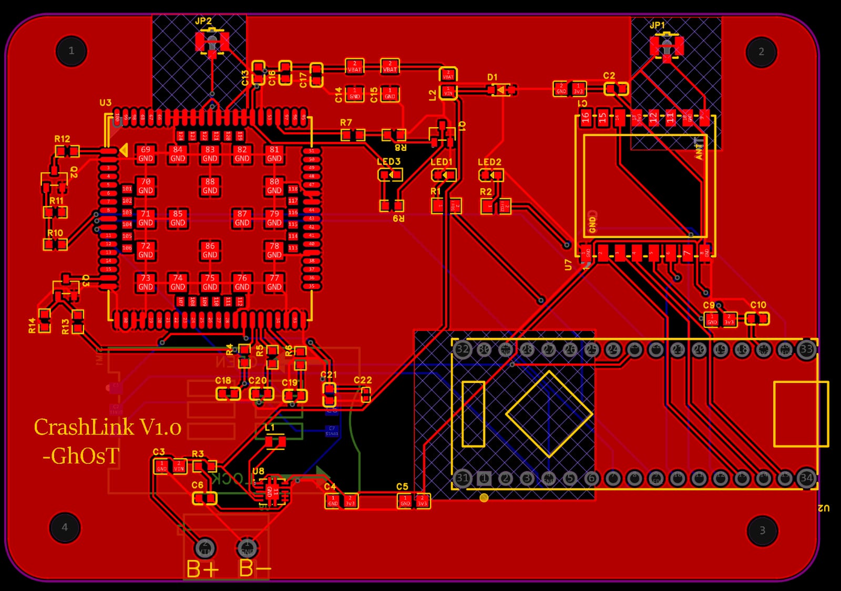
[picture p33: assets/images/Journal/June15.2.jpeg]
PCB Gateway Node

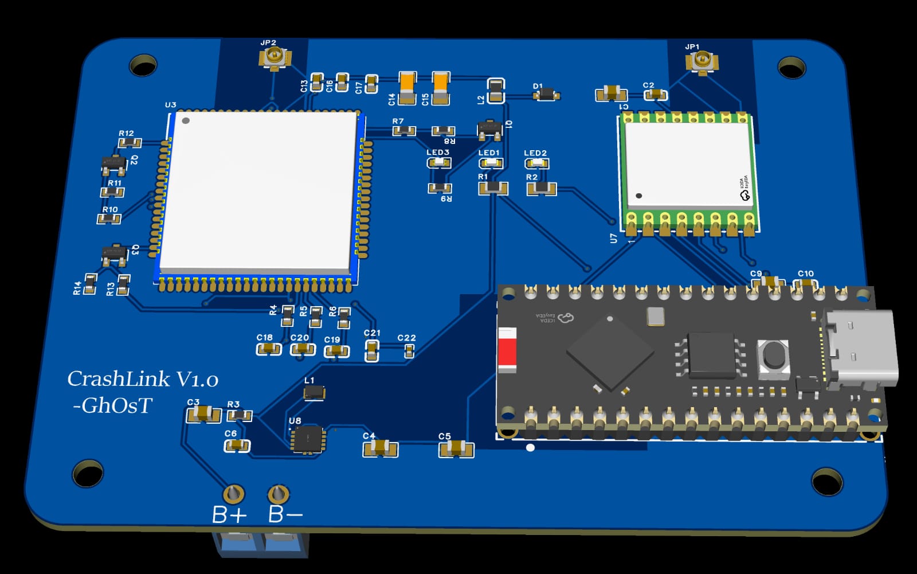
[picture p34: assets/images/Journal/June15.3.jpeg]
3D Gateway Node

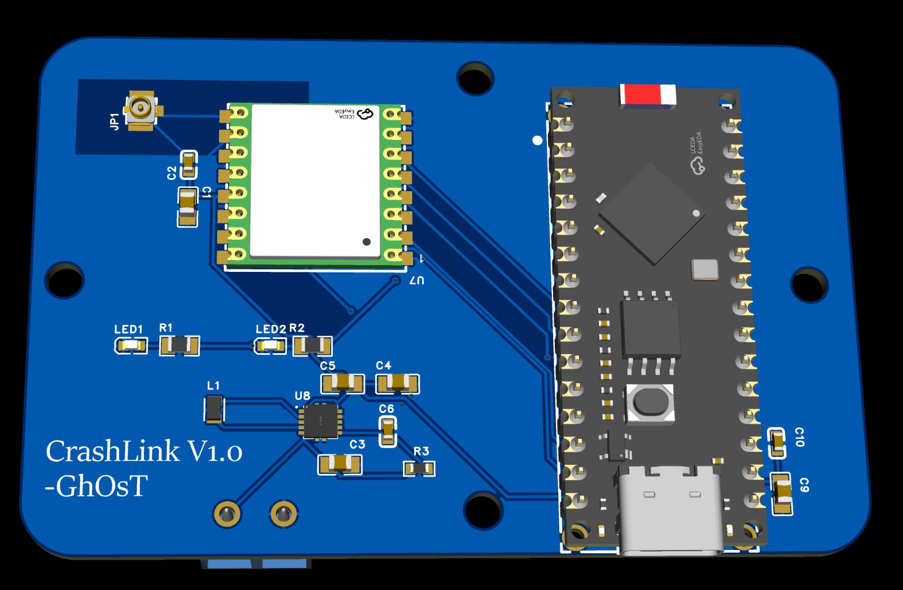
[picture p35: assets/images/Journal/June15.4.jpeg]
3D Relay Node

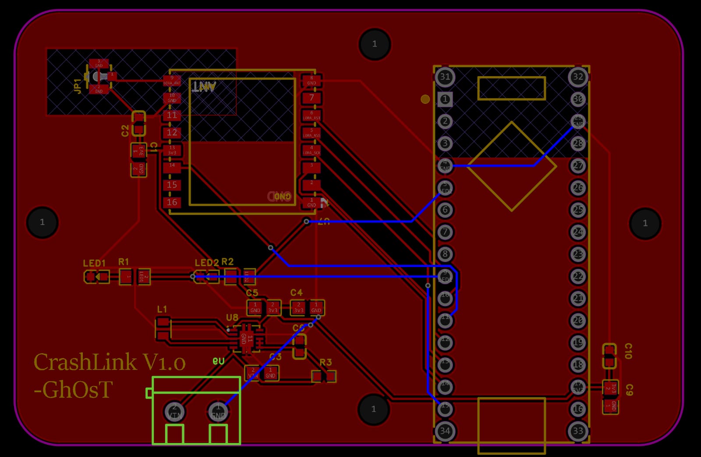
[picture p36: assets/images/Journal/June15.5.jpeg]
PCB Relay Node

- [Lapse PCB Designing](https://lapse.hackclub.com/timelapse/PSA4Y4LY7QzS)
**Total time spent: 2 hours 40 minutes**

# June 16 : Starting with enclosure Design
Downloaded and did setup for Fusion 360
started designing enclosure but suddenly the laptop freezeed.
Still I tried to fix it and then later I shifted to learning the designing
likw basic movements tools inside fusion 360.

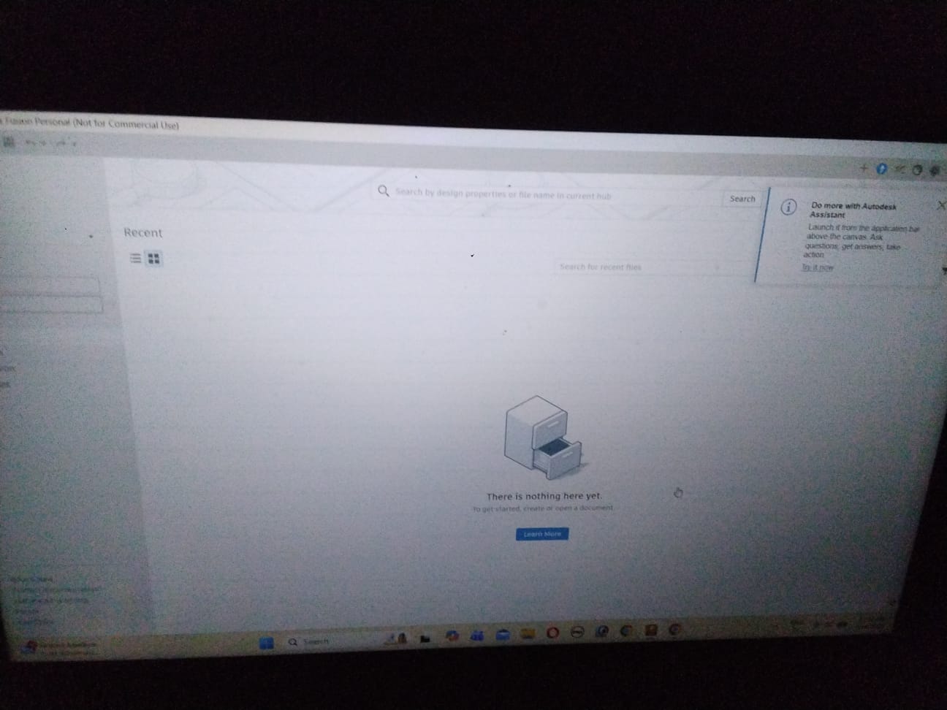
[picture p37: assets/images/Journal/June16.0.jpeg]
Fusion 360 Setup

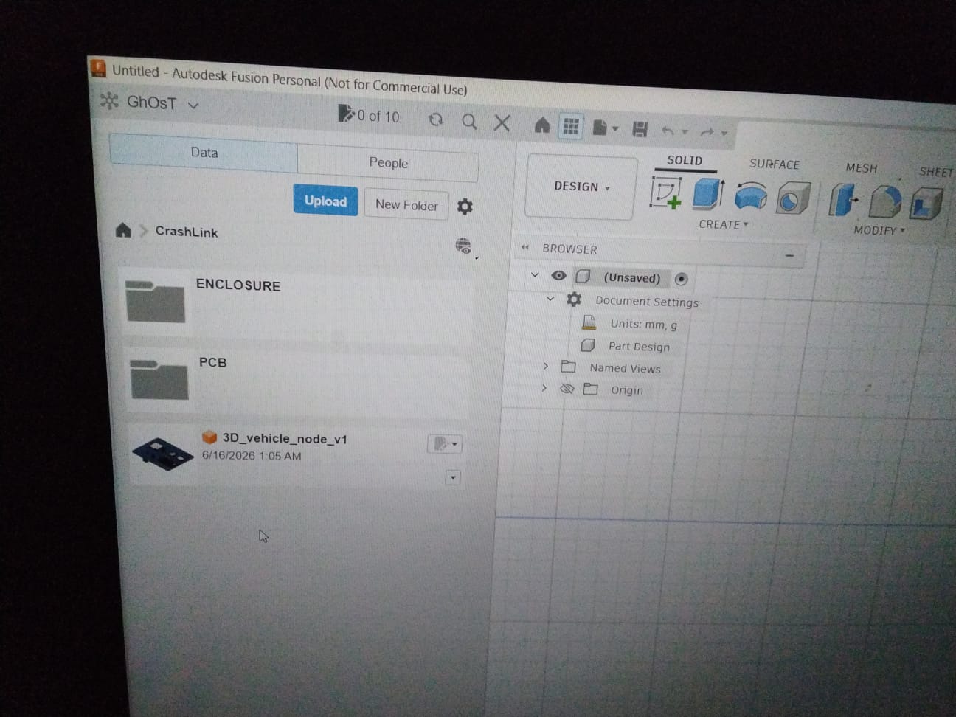
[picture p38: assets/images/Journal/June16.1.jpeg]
Importing File


**Total time spent: 1 hours**

# June 17 : Found flaws in Vehicle Node PCB Design
Found some flaws in my vehicle node pcb design
- No Antenna connector for GPS
- No pllup resistors for MPU6050

Explored the data sheets and used AI for debuging this new found issue
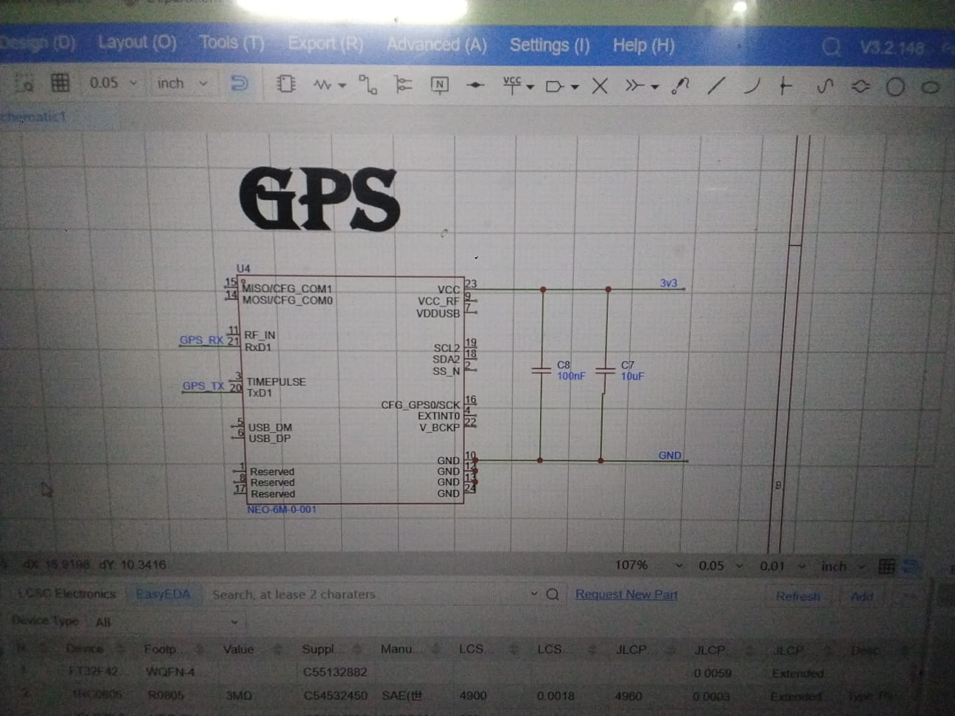
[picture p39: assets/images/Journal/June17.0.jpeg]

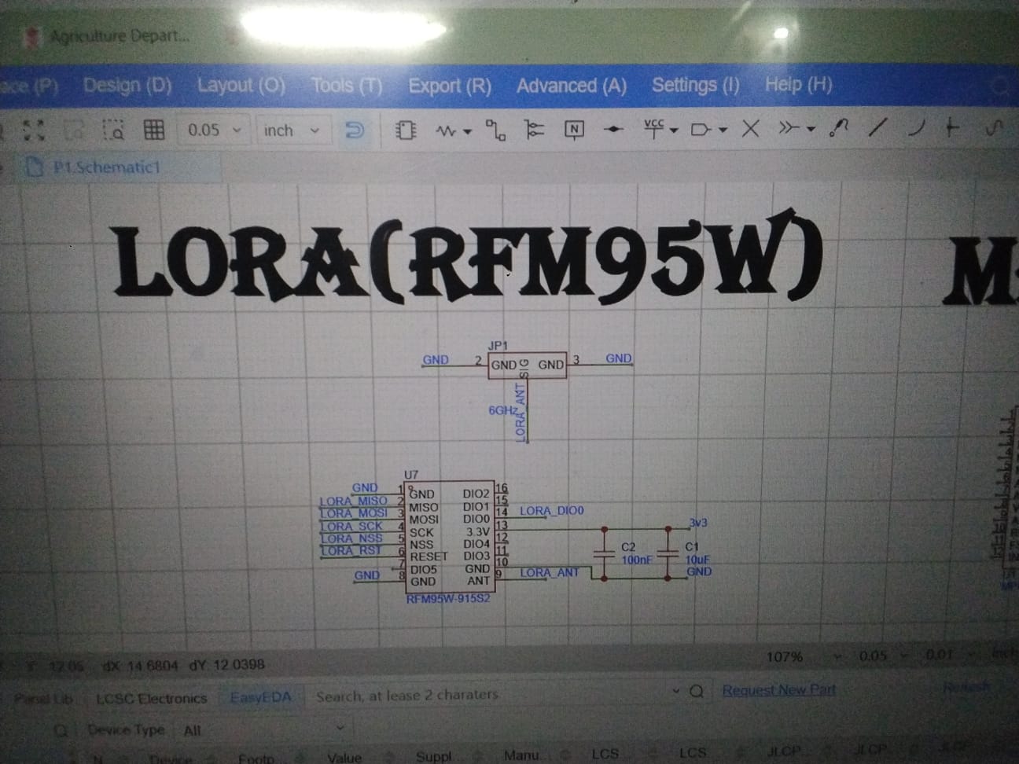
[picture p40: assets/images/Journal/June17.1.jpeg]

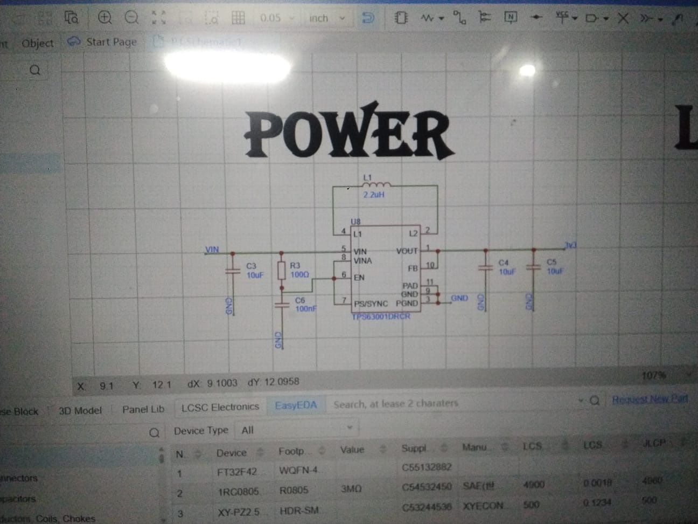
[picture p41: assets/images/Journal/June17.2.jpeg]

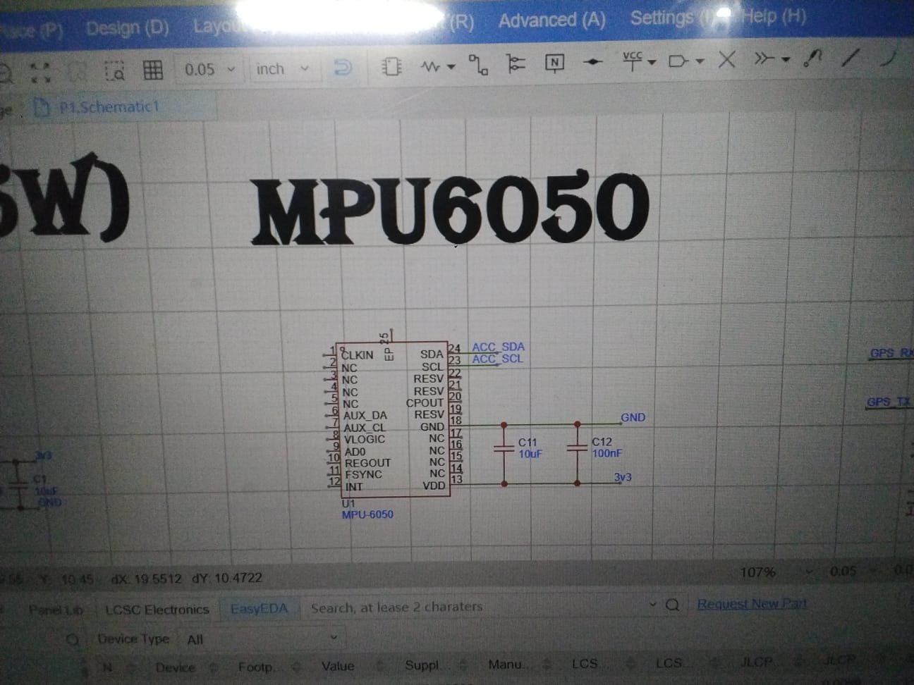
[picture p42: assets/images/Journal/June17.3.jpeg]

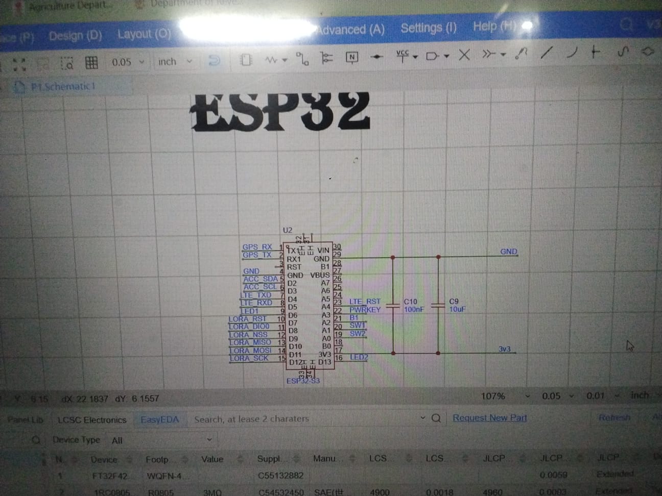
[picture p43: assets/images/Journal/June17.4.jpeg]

Faults Analysis
Faults Analysis

**Total time spent: 2 hours**

# June 18 : Finally PCB Design done
I swear this is the final redesign no more change.
Finally I did follow everything as per whatever i found in the datasheets 
I redesigned the schematics of vehicle node then reorganized
all the nodes PCB designs enjoy the lapse.

PCB Design
PCB Design
PCB Design
PCB Design
PCB Design
PCB Design
PCB Design
PCB Design

- [Lapse](https://lapse.hackclub.com/timelapse/Fn2Z4zk5b6SL)

then off the lapse i exported files and did some documentation.

**Total time spent: 4 hours 30 minutes**

# June 19 : Started Enclosure Design
Tried to do Enclosure design but it didn't workout.
So like I did gave an hour but it took so much time to figure out how this thing works.

Enclosure Design
Enclosure Design
Enclosure Design
Enclosure Design

**Total time spent: 1 hours**

# June 20 : Enclosure Design completed

Finally Done with the Enclosure Designing
- **VehicleCase** took the longest 2 and half hours coz I wasnt familier with this tool yet.
- **RelayCase** would have taken less time but due to some orientation error while exporting it took 30min just to get started with the designing thing and then it took like 1hr to complete the design.
- **GatewayCase** Past learning showed up here and got done with the
 designing in just 45 min.

Enclosure Design
Enclosure Design
Enclosure Design

After all this did some documentation took around 20 min

**Total time spent: 5 hours**

# June 21 : Final design documentation
- Exported PCB and Enclosure designs
- Renamed the file names for better readability
- Organized exported files into repository structure
- Deleted Old design files
- Added Journal Entries

Documentation
Documentation

**Total time spent: 2 hours**

# August 5 : RF matching network fix

Got the feedback about the lack of  pi-matching network so
I fixed it as per the reference design of A7670C-LANS datasheet.

Documentation
Documentation
Documentation

I am still not sure of the trace width so it might need some change.
firstly I started with the vehical node pi matching network for A7670
then I did it for GPS aswell but but I dont  think it was needed for the GPS.

- [Lapse](http://lapse.hackclub.com/timelapse/U3hexZDmZmPl)
- [Lapse](https://lapse.hackclub.com/timelapse/aronYUaw0zdo)
- [Lapse](https://lapse.hackclub.com/timelapse/7AQ2QLC01Yy2)

Although I finished this still i do feel something is missing here.

**Total time spent: 3 hours 10 minutes**

# August 7 : Reviewing the designs and Finding Flaws

After looking at my current design which uses ESP32 Waveshare Board(An expensive board around 11 dollars)
so I made my mind to reduce the cost by droping the ESP32 Waveshare devkit board.
I researched a bit and found out that ESP-32 WROOM32E N8 module is a good alternative
and its better to redesign the board around this module instead of using  devkit.

Documentation

so I searched for the datasheets and got ESP32 devkitC v4 reference designs
which was very reliable so i decided to use it as an Inspiration.

Documentation

Also I decided to Replace the NEO6m with MAX-M10S as this is newer module
and multiple hardware creators and forums suggested using this one(since i was already gonna be redesigning so no issues).

Documentation

The new GPS module also contains internal LNA and SAW filters making it more reliable and less hassle.
**Total time spent: 35 minutes**

# August 9 : Updating the Schematics with new Components & correcting past mistakes

Corrected mistakes in the MPU-6050 by following the Datasheets & took Some help from AI aswell as I was completely stuck.
I could not find much of reference designs for this so I used external reference from adafruit's design.
Documentation

Added new components GPS(MAX-M10S) Spent good time on Reading its Datasheets and closely following its Reference designs.

Documentation

- [Lapse](https://lapse.hackclub.com/timelapse/a8KgVX0sD21Z)

**Total time spent: 1 hours 19 minutes**

# August 10 : Completed Schematics and Made it look less messy

Started updating where i left yesterday.
Documentation
struggled in finding the right connections and spent whole lot of time in the Datasheets and reference designs and also took some AI help in knowing if i am getting the things right or not.
Documentation
for example I replaced the nomal USB connector to USB C for programming
Documentation
Documentation
and i got stuck at doing the connections right since things got different from reference designs .
Documentation
Documentation

then i re checked everything and made  the GSM cluttered seperated parts into one block

I also re organized the whole schematics to make it look good  like boxed the different sections and wrote what each sections do.

-[Lapse](https://lapse.hackclub.com/timelapse/juxAB3uTijgG)

**Total time spent: 4 hours**

# August 12 : Sanity check myself plus AI(Ai not reliable I know)

So I Had Almost completed the Schematics and organized it as well
but while doing this 4 hr session my brain got fried and i did many mistakes.

Documentation

I already had this feeling so I decided to match the schematics resistor by resitor and capaxitor by capacitor to see if each value matches or not.
Documentation
Documentation
Documentation
Documentation
Documentation
AI Flagged Many issues which I crosschecked with the Datasheets

-There were some issues with value of resisors and capacitors for many connections which i fixed.
-Two switches for EN & IO0 was not connected so I fixed that issue aswell
-Then I did sent Ai to check if everything is okay or should I change things 
-They gave some useful and some suspicious insights 
-Two pins AD0 and FSYNC was left floating (Good insight)
-REGPIN needs to be connected to capacitor(It was already connected lol)
-A7670 rF matching circuit being different from datasheets(it wasnt i checked or maybe if it was i will ask reviewrs to flag it idk)
-MAX-M10S needs filter circuit(The datasheet said its not needed as internal filter(LNA & SAW) Provides enough gain even with passive antenna and no matching network still I added one matching circuit)

-[Lapse](https://lapse.hackclub.com/timelapse/Z1DkRJ5dDHLi)

**Total time spent: 2 hours 50 minutes**

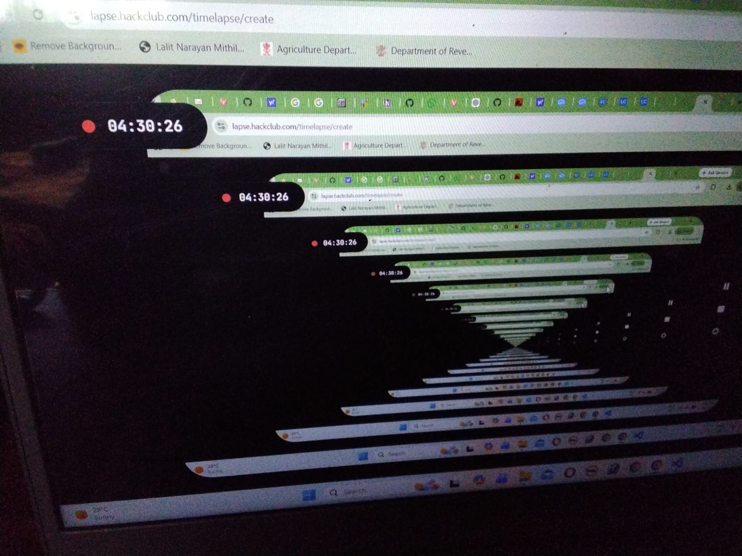
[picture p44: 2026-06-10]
assets/images/Journal/June8.1.jpeg

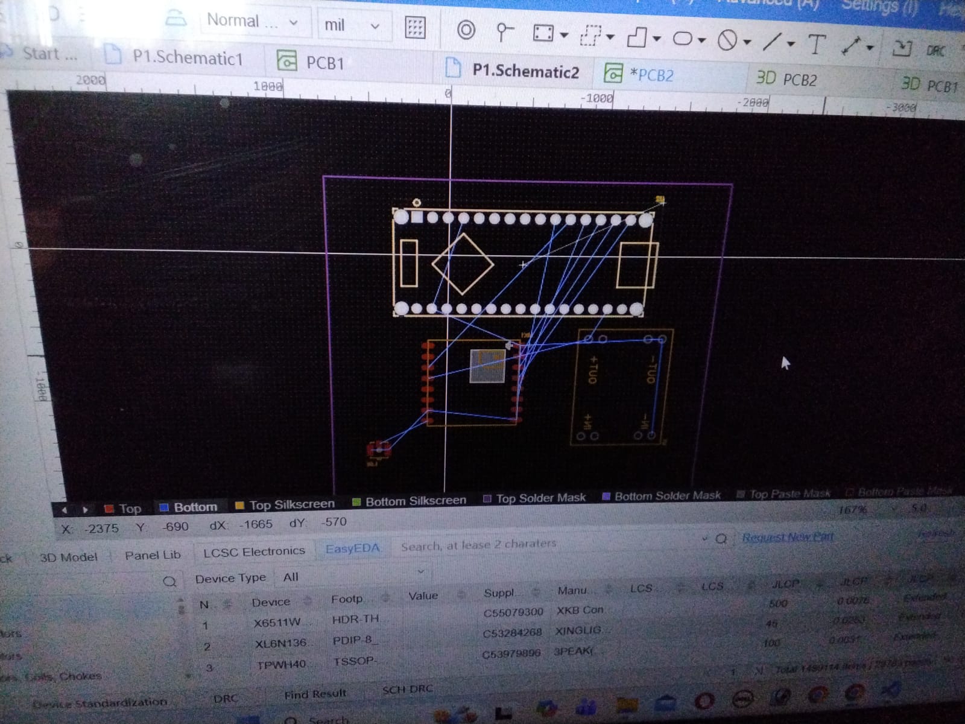
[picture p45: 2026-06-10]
assets/images/Journal/June8.3.jpeg

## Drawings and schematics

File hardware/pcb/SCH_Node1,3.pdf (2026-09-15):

# GND 10 DIO3 11 DIO4 12 3.3V 13 DIO0 14 DIO1 15 DIO2 16

Accelerometer(MPU-6050) | GPS(MAX-M10S)

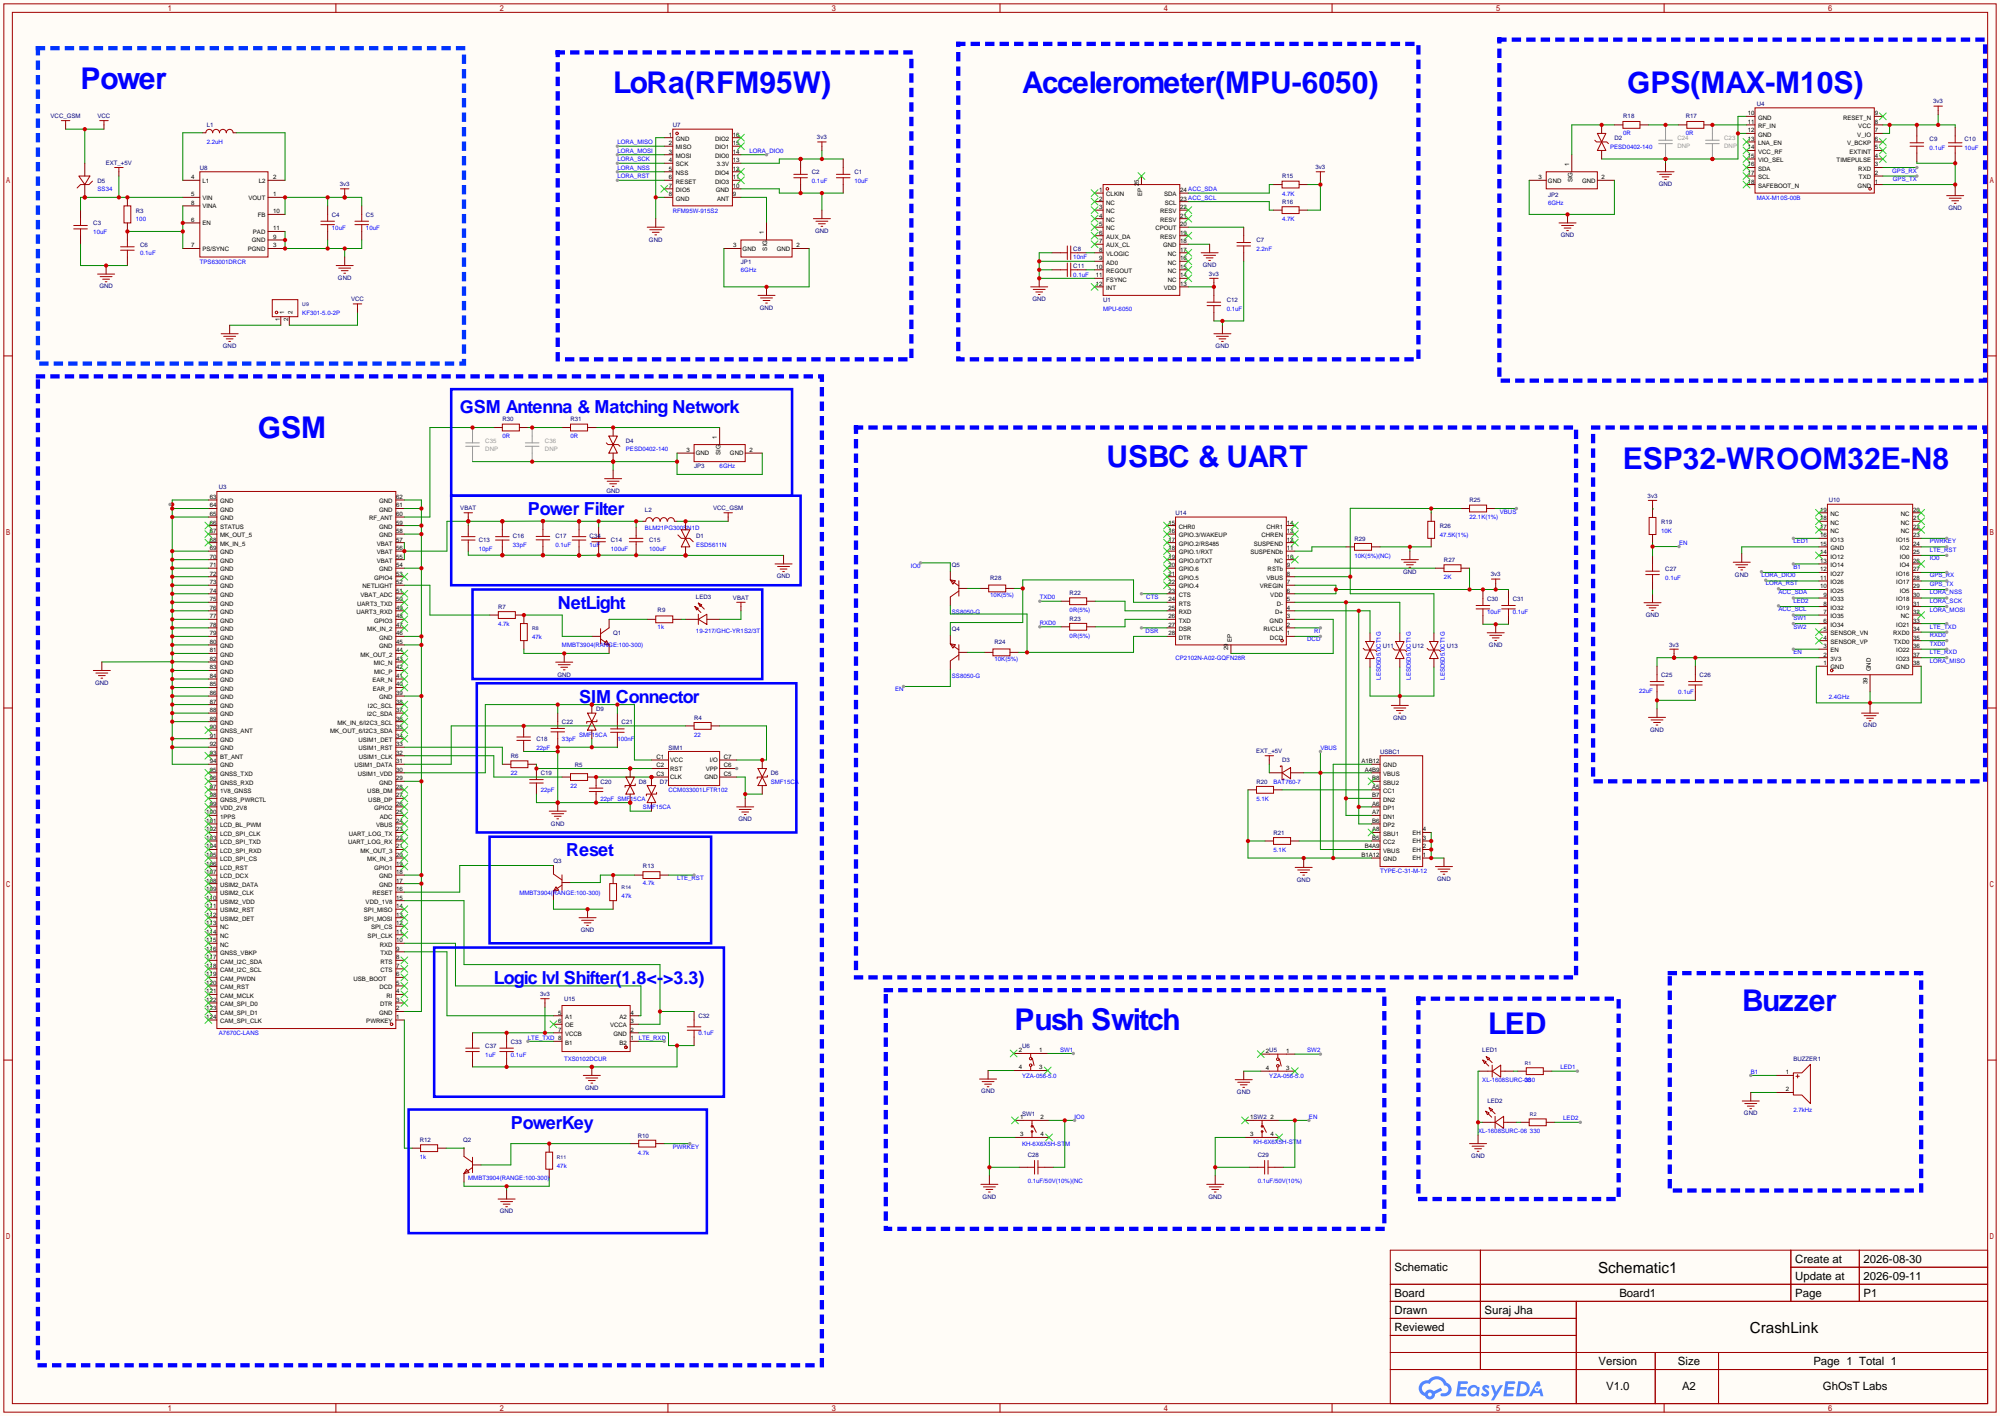
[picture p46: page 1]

GSM Antenna & Matching Network

GND 58 GND 59 RF_ANT 60 GND 61 GND 62 GND 63
GND 64
GND 65
STATUS 66
MK_OUT_5 67
GND 69
RXD 10 SPI_CLK 11 SPI_CS 12 SPI_MOSI 13 SPI_MISO 14 VDD_1V8 15 RESET 16 GND 17 GND 18 GPIO1 19 MK_IN_3 20 MK_OUT_3 21 UART_LOG_RX 22 UART_LOG_TX 23 VBUS 24 ADC 25 GPIO2 26 USB_DP 27 USB_DM 28 GND 29 USIM1_VDD 30 USIM1_DATA 31 USIM1_CLK 32 USIM1_RST 33 USIM1_DET 34 MK_OUT_6/I2C3_SDA 35 MK_IN_6/I2C3_SCL 36 I2C_SDA 37 I2C_SCL 38 GND 39 EAR_P 40 EAR_N 41 MIC_P 42 MIC_N 43 MK_OUT_2 44 GND 45 GND 46 MK_IN_2 47 GPIO3 48 UART3_RXD 49 UART3_TXD 50 VBAT_ADC 51 NETLIGHT 52 GPIO4 53 GND 54 VBAT 55

Schematic | Schematic1 | Create at | 2026-08-30

Update at | 2026-09-11

Board | Board1 | Page | P1
Drawn | Suraj Jha | CrashLink
Reviewed

Version | Size | Page 1 Total 1
V1.0 | A2 | GhOsT Labs

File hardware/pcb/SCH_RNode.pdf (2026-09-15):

# GND 10 DIO3 11 DIO4 12 3.3V 13 DIO0 14 DIO1 15 DIO2 16

# ESP32-WROOM32E-N8

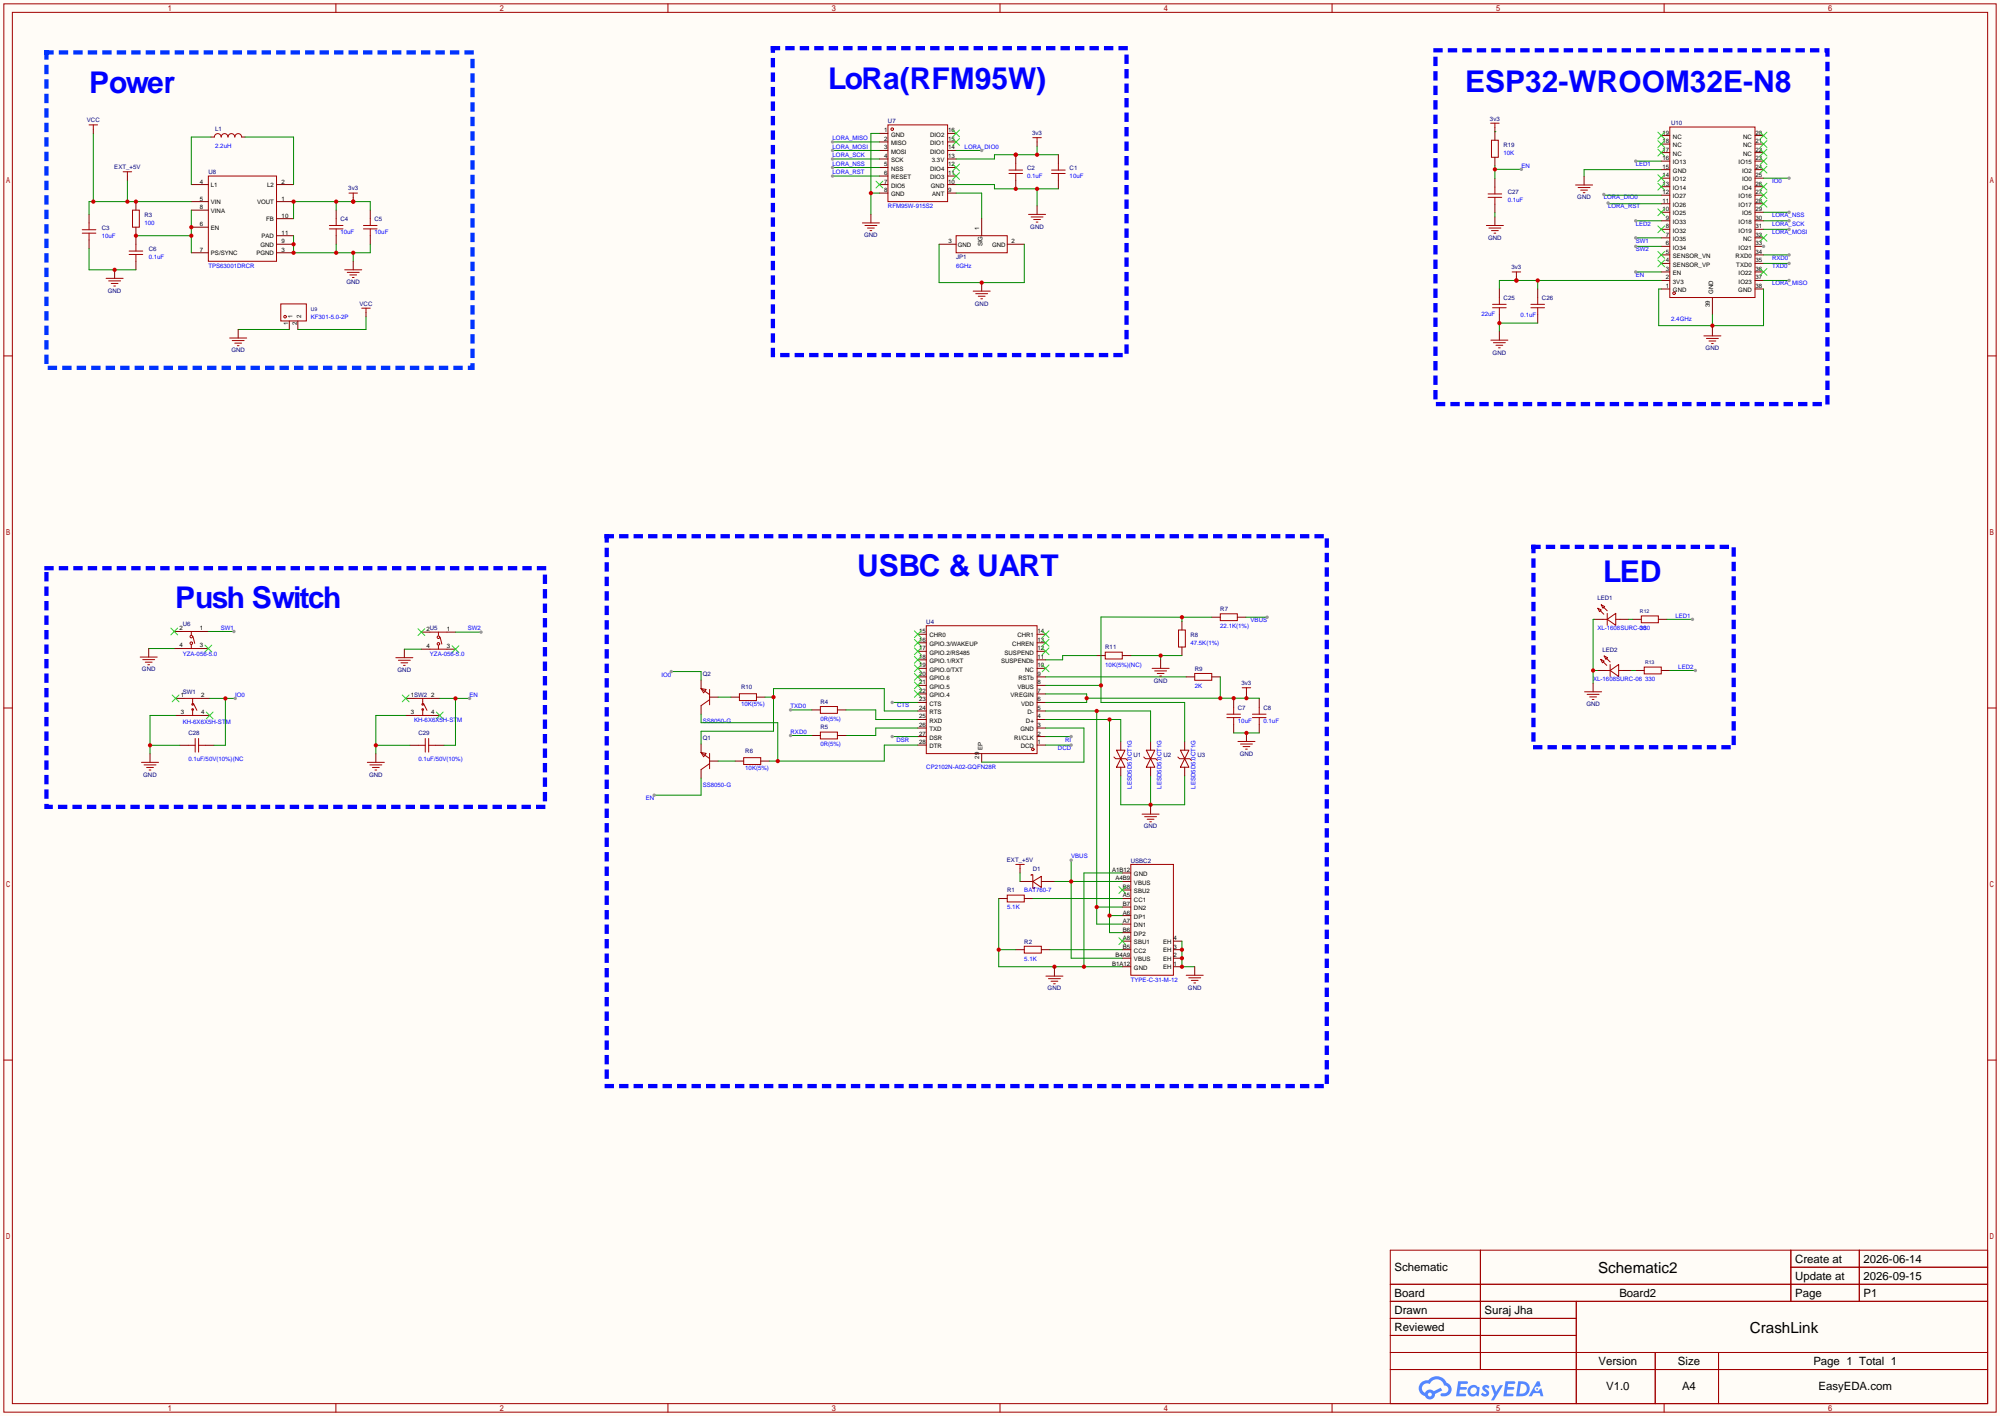
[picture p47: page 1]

Schematic | Schematic2 | Create at | 2026-06-14

Update at | 2026-09-15

Board | Board2 | Page | P1
Drawn | Suraj Jha | CrashLink
Reviewed

Version | Size | Page 1 Total 1
V1.0 | A4 | EasyEDA.com

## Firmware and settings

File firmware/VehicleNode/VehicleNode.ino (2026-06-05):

#include <LoRa.h>
#include <Wire.h>
#include <SPI.h>
#include <SoftwareSerial.h>
#include <Adafruit_Sensor.h>
#include <Adafruit_MPU6050.h>
#define THRESHOLD 15.0


Adafruit_MPU6050 mpu;


void setup () 
   {
      Serial.begin(115200);
      if (!mpu.begin()) {
        Serial.println("Failed to find MPU6050 chip");
        while (1);
        }
      }
          
   };
void loop () 
   {detectCrash();
      if (totalAccel > THRESHOLD) {
      Serial.println("Crash detected! Sending alert...");
      sendAlert();
   }
          
   };

void detectCrash() {
  sensors_event_t a, g, temp;
  mpu.getEvent(&a, &g, &temp);
  float totalAccel = sqrt(sq(a.acceleration.x) + sq(a.acceleration.y) + sq(a.acceleration.z));
   
}

void sendAlert() {

  LoRa.beginPacket();
  LoRa.print(alertMessage);
  LoRa.endPacket();
}  

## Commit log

2026-06-04 Create RelayNode with setup and loop functions
2026-06-06 Add documentation files for project architecture, BOM, and testing
2026-06-08 Add crashlink_vehicle_node_v1.0 schematics PDF to hardware directory
2026-06-08 Add crashlink_vehicle_node_v1.0 Gerbers ZIP file to hardware directory
2026-06-10 Update README.md to enhance project overview and detail current progress
2026-06-10 Update architecture.md to enhance vehicle, relay, and gateway node descriptions for clarity
2026-06-10 Add Bill of Materials (BOM) documentation with detailed components and estimated costs
2026-06-10 Fix formatting in Bill of Materials for improved readability
2026-06-10 Update Bill of Materials with estimated costs and correct section titles for clarity
2026-06-10 Update Bill of Materials with corrected estimated costs and descriptions for clarity
2026-06-11 Add 3D enclosure file tasks for Vehicle, Relay, and Gateway Nodes in progress section
2026-06-12 Refactor Current Progress section to add revision notes for Vehicle and Relay Node tasks
2026-06-15 Refactor Current Progress section; remove revision notes and update image paths for Vehicle, Relay, and Gateway Nodes
2026-06-15 Remove obsolete Vehicle Node files: Gerbers, schematics, and images
2026-06-15 Add vehicle node hardware files including Gerber, PCB image, and schematic
2026-06-21 Update gateway node PCB files: add new BOM, Gerber, and schematic files; remove outdated files
    [BOM_gn_v1.xlsx, PickAndPlace_gn_v1.xlsx]
2026-06-21 Update vehicle node PCB files: add BOM, Gerber files, and schematic images; remove outdated files
    [BOM_vn_v1.xlsx, PickAndPlace_vn_v1.xlsx]
2026-06-21 Update relay node PCB files: add BOM, Gerber files, and schematics; remove outdated files
    [BOM_rn_v1.xlsx, PickAndPlace_rn_v1.xlsx]
2026-06-21 Add CAD files for all 3 nodes
    [GatewayCase_v1.step, RelayCase_v1.step, VehicleCase_v1.f3d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]
2026-06-23 Add new journal images and BOM file; remove outdated screenshot
2026-06-23 Refactor README.md: reorganize node sections, update PCB views, and correct enclosure file entries
2026-07-07 update bom.csv file
    [bom.csv]
2026-08-08 Add PCB Design files
    [BOM_gn_v1.xlsx, BOM_rn_v1.xlsx, BOM_vn_v1.xlsx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]
2026-09-15 remove bom.md
2026-09-15 add bom section and update image path
2026-09-17 fix: correct image paths for Relay Node PCB views
2026-10-13 add : PCB Design files
2026-10-13 Add CAD files for enclosure designs
2026-10-13 add: update README.md with new enclosure images
2026-10-14 add: initial code for Vehicle, Relay and Gateway Nodes
2026-10-22 add: update JOURNAL.md with details on Vehicle Node case cover text
2026-10-22 fix: update Relay Node enclosure image to relay_node0.png
